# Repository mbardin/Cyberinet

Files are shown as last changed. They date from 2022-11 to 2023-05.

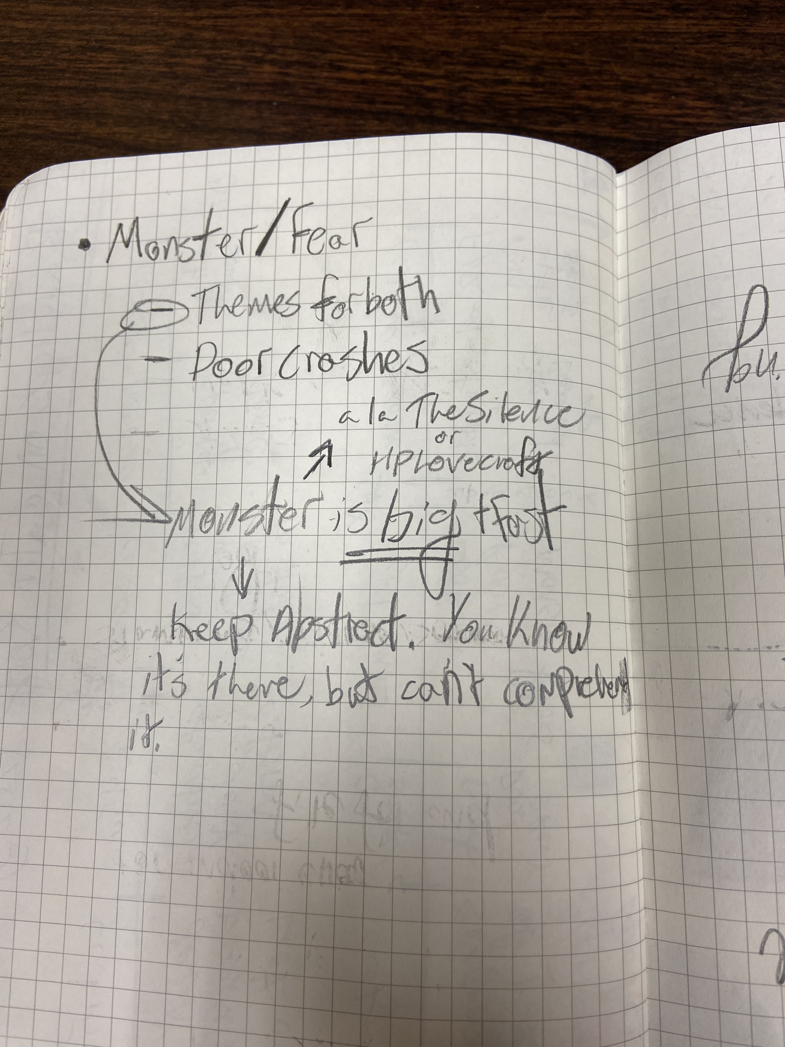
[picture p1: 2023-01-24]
zMusic Composition Scores/scores/materials/raindrops/planning diagrams/IMG_1224.JPG

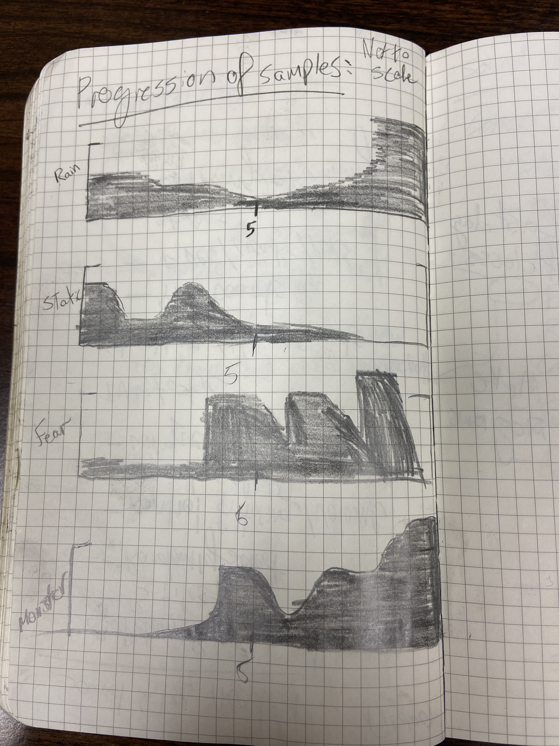
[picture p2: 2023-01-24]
zMusic Composition Scores/scores/materials/raindrops/planning diagrams/IMG_1223.JPG

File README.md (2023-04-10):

# Cyberinet: Integrated Semi-Modular Sensor Interface for Computer-Augmented Clarinet
 Collection for all assets related to the Cyberinet
 
 A Dissertation Project by Matthew A. Bardin [2023]. These Materials are submitted in partial requirements for the degree of doctor of Philosophy in the field of Experimental Music & Digital Media at the Louisiana State University and Agricultural and Mechanical College.

 The goal of the Cyberinet is to bring computer augmentation to the clarinet with minimal additions and adjustments to the performer's traditional practices. The final version is integrated into a special 3D printed clarinet barrel that can easily replace the standard barrel to instantly add augmented capabilities to the instrument.

 ## SYSTEM COMPATIBILITY
 Versions 1.X currently are only supported on Mac OS operating systems. This is mainly due to how Windows-based systems handle incoming and outgoing serial communications. This problem could potentially be worked around by a user with sufficient knowledge of those systems, but it is the main priority to have the Cyberinet easily functional on all main operating systems for version 2. Outside of the serial communication, all of the other Cyberinet software components are compatible with both Mac and Windows.

 ## FIRST TIME INSTALLATIONS
 When utilizing the Cyberinet for the first time, a few items will need to be installed on your device. First, if you do not have Node and the Node Package Manager (NPM) installed, these will need to be included for the data transmission. You can check the installation in the Terminal program on Mac devices. Typing the prompt `which npm` will return the version of npm installed on the device. If the program is not installed, the terminal will indicate so. You can install npm with the terminal command `npm install`, or at https://nodejs.org/en/download

 Once this is installed, there are only two more steps. Next, if you do not already have it installed, install the Arduino IDE from https://www.arduino.cc/en/software. This is the program used for programming the Cyberinet and can be utilized for easily installing the microcontroller drivers. Once installed, navigate to the IDE's preference menu, and notice the item labelled `Additional Boards Manager URLS` and enter the following url in the box: `https://espressif.github.io/arduino-esp32/package_esp32_index.json` When complete, you can navigate to the IDE's Board manager and install the ESP32 library that will now appear in the board manager. Once this is installed, you will not need to use the Arduino IDE again unless you wish to reprogram or make a duplicate of your Cyberinet.

 If you do not currently have Max installed, it can be downloaded from https://cycling74.com. The program can be purchased, and has an educational discount, but purchasing is not required unless you wish to program your own patches for use with the Cyberinet. Patches made by others can be utilized without purchasing the software.

 The final installation will be covered as part of the wireless communication section of this document.
 
 ## Wireless Communications
 The Cyberinet communicates with a host computer using Bluetooth connectivity. The device will appear as "CyberinetVXX" indicating the software version. 
 _As a trouble shooting tip, before performing with the Cyberinet first un-pair and re-pair the Cyberinet with the host computer._ 

 To begin communications, first power the device and navigate to your computer's bluetooth preferences. Select the Cyberinet to pair with the device.
 Then, open the object `CNET.test` in Max. This object is designed to help with setting up the Cyberinet and ensuring the communications can be received. Follow the instructions in the patch, but keep note of step 0. If you have not utilized node scripts in Max previously, you will need to install the final component by sending a bang into the right-most inlet of the object (right-most button in the test patch). From there, you can begin Utilizing the Cyberinet by following the on-screen instructions. 

 When listing the available communication ports, you will see them listed in the Max console. If it appears as something other than `/dev/tty-CyberinetV13` (the final number indicates the software version), then enter the given port name in the provided message box prior to enabling the communications.

 ## Device Ports
 The internal Lithium Polymer battery can be charged with the Cyberinet's USB-C port. The device can function while charging, but only transmits data using Bluetooth communications.
 The ESP32 DEVKIT contains a micro USB port. This is only utilized for flashing adn updating the microcontroller, and is not accessible without disassembling the device.

 ## Printed Circuit Boards
 The Cyberinet is available for purchase including all of the components pre-set up. However, the materials are all open source and can be created using the included PCB diagrams, Arduino code, and other materials in this repository.
 
 ## OEM Components
 The Cyberinet contains the following OEM Components listed in the BOM:
 * ESP32 DEVKIT V1
 * MPU 6050 6-axis Gyroscope
 * TP 4056-C
 * SparkX Differential Pressure Sensor 

  _A second troubleshooting tip. If the Cyberinet does not power on when the button is pressed, first try pressing the button 4 times in a row. If that does not work, connect the Cyberinet to a charger. A short connection can be enough to jump the device to life, but it is recommended to fully charge the Cyberinet immediately prior to a performance._ 
 
 ## Hardware
 The casing for the hardware is 3D printed. .stl files can be found in the repository. The form factor of the Cyberinet is designed to temporarily replace the barrel of a traditional Bb clarinet.
 You cn also find the .gcode files for the 3D printed hardware here as well.
 
 ## Code
 The Cyberinet is programmed using the Arduino IDE. The main unit comes with the most up-to-date firmware version already included. Reprogramming the Cyberinet is not recommended as accessing the necessary port will result in the permanent unsealing of the device, which will lead to rattling in the unit and potential damages due to any internal gluing and other supports being altered.
 
 ## Max Patches
 The included Max patches can be used to create various audio and visual processes using the data received from the Cyberinet. Several examples and help patches are currently in development.

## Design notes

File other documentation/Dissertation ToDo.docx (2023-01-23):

# Hardware

- Order more ESP32, airflow boards, gyro, and power boards
- Choose connector type
- Finish soldering main and button boards
- Design box with new size measurements
- Model version of box with and without mouthpiece. See which one works the best
- Buy batteries. As big as possible while fitting in the container
- Design pitch sensor

# Software

- Create reverb
- Create compressor
- Create filter
- Create delay
- Create pitch analyzer

# Music

- Revise first two comps
- Make ethereal score pretty
- Make puzzle score pretty
- Write and format raindrops

# Document

- Discuss all 3 music comps
- Break down the build and software
- Historical context

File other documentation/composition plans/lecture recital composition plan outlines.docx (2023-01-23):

# Ethereal presence:

Music material comes from my bass clarinet concerto with expansions for a better flow

Uses gyro/accel to control the synth

Mixes between longer, slower tones and fast runs.

Extremely open structure. Idea is that each performance will be different.

Two main synth types: more textures and melodic. May look into fixing to certain pitches a la auto tune.

# Puzzle of a Park:

A loop pedal style. Performer uses the two main buttons to trigger recording and playback

How the buttons work:

Performer needs to start the recording and playback in time.

Control mixing of the 4 voices via air flow

# Raindrops on a Tin Roof:

Longer than the other two compositions. Utilizes everything except the buttons

SCARY

Control the triggering of sound files with pitch analyzer portion of the device

Control mixing of various playback with airflow

Control timbre with gyro

Control tempo with accel

Have pages of score broken up between 3 different stands with rapid running between sections

Rain and wind sounds as part of backing

Trigger monster and other ambience sounds with pitch analysis

Run between stands to make more out of breath over time. This change will trigger more monstrous playback transformation

Follows the story in terms of structure:

1. Rainy night
2. Falls asleep and wakes up
3. Things not quite right
4. Goes to basement
5. Finds monster
6. Runs away
7. Monster changes
8. Gets to top floor
9. Followed
10. Panics and runs outside before being killed

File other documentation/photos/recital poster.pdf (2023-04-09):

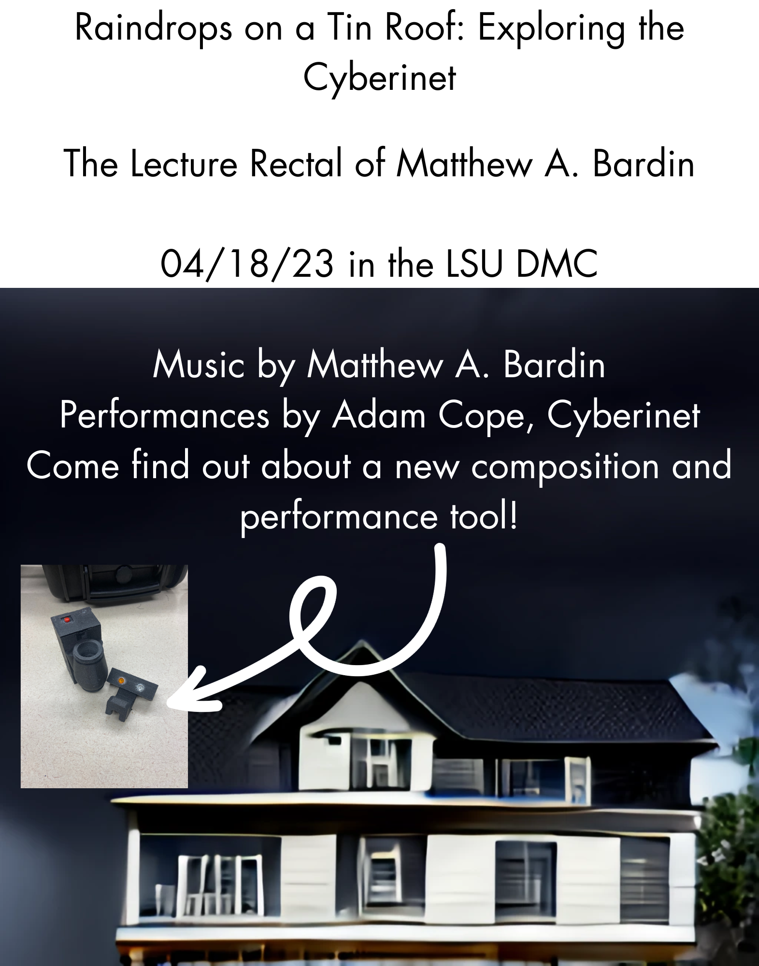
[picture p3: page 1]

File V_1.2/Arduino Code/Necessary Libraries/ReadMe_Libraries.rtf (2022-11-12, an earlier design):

Readme: Cyberinet Libraries

If you would like to change the code running on your Cyberinet, or need to update the code, you will need the libraries included here in order for the code to compile.

First make sure that your board is set to “DOIT ESP32 DEVKIT V1” and that the following libraries are included:
Wire : Installed from the Arduino IDE Library Manager
Sparkfun_SDP3x_Arduino_Library : Must be installed from .zip folder
BluetoothSerial : Installed from the Arduino IDE Library Manager
MPU6050 : Install from the Arduino IDE Library Manager

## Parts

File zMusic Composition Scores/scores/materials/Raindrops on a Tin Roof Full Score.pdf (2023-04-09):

# Raindrops on a Tin Roof

# for Cyberinet, pre-recorded sounds, and live electronics

# Matthew A. Bardin

2023

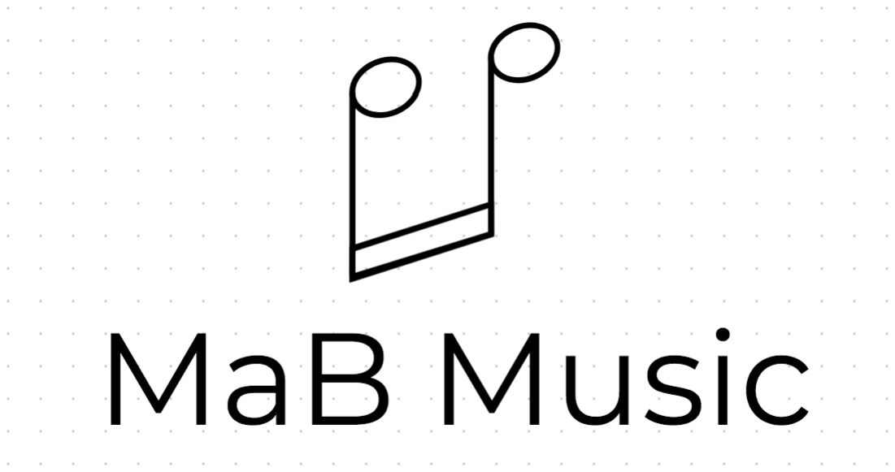
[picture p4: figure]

Program Note:
A short story. An event. When you are the most comfortable, that is when the unknown can strike. Usually in a way we least expect. How can one respond to the uncomprehendable?
Approximately 12-15 minutes in duration. Completed March 15

th 2023 in Baton Rouge, LA MaB

Performance Notes:
For the Performance of Raindrops on a Tin Roof, a unique setup can be utilized. The theatrical stage setup is not required, but highly encouraged by the composer if possible as they enhance the atmosphere.

The performer should arrange three stands across the width of the stage. When instructed in the score, the performer should move from their current stand to the indicated stand. A smoke machine should be placed upstage and off-center of the performer to minimize its visibility from the audience. The smoke machine should be set to approximately medium-low. There should be a low mist/fog that picks up the lights in the room, not so much that it becomes obstructive.Two DMX-controlled lights should be placed slightly downstage of the performer, illuminating the stage. Stage lights should be turned off, but if needed spotlights, stand lights, or low-level lighting can be used to illuminate the three stands for the performer. Will all of the staging, the performance space should look like this:

Smoke Machine

3 | 1 | 2
Light | Light
| Audience

The following Performance Pages should be on the stands as shown below:

1. Pgs 1-2, 4-5, 9-10
2. Pgs 5-8
3. Pgs 2-4

Multiple stands at some stanf locations may be needed.

Adjustments to the staging can be made depending on the specifics of the performance venue. The atmosphere should be spooky, and as if rain will begin at any second. A fan is recommended to help dissipate the smoke following the performance.

Tempo markings should be observed as close as possible. Tempi indicated are those of the synthesizer accompaniment sound files. When the “as fast as possible” instruction occurs, the performer should play the section as fast as possible while still maintaining rhythmic and pitch integrity. Do not worry about playing in time with the synthesizer during these moments. There will be a moment to return to being in time with the synthesizer indicated with the button.

On Software:
The Raindrops on a Tin Roof Max Patch is required for the performance. This patch can be downloaded from matthewbardin.com/raindrops. If needed, Max (Version 8.5 or newer needed) can be downloaded from cycling74.com. It is not required to purchase the software as the patch will run in demo mode, however it is recommended if possible as purchasing the software will unlock editing and saving of patches.

The Max patch will take data from the Cyberinet’s embedded sensors and use them to process sounds as shown below:

Gyroscope: Used to control reverb and panning Accelerometer: Used to control DMX Lights, playback volume, and delay Airflow: Used to control DMX Lights, playback volume, and distortion Button 1: Used to cycle through settings and trigger audio clips Button 2: Emergency Mute All switch

Largely speaking, the Cyberinet controls the volume of various sound files on playback, as well as the processing to those sound files. The clarinet timbre is the only element with no processing applied to it.

There are three categories of sound files used in Raindrops on a Tin Roof:

1. Synthesizer Accompaniment: Unnatural, distorted sounds to accompany the clarinet timbres.
2. Ambiance: Digetic sounds occurring in the story as it unfolds. These include rain sounds, monster sounds, and creaking floorboards
3. Narrator: Recordings of the composer reading the story. These are used to provide context to the music as it is happening. Generally the music pauses during these moments.

On Hardware:
The performer will need the Cyberinet as well as the button expansion to perform Raindrops on a Tin Roof. In addition to the items listed under ‘Performance Notes’, The performer will require a computer to run the software patch. This computer can be either Windows or MacOS. The software patch will run on either devices. A USB-to-DMX adapter for each of the lights are also needed as they will be controlled from the max patch.

On Notation:
Cross Noteheads: Indicate pressing Button 1 to progress to the following section of music.

Vamp: Repeat the indicated music as many times as wanted or needed. Each vamp should occur at least 3 times. All other repeats occur once.
Travel Instructions: Tell the performer their method of moving from one stand to another. This text is always underlined.

Movement Indicators: Indicate exaggerated movements or breathing.
Exaggerated movements should generally be swaying or small steps to trigger the gyroscope more.

Exaggerate breathing should be heavier and more frequent breaths than normal in order to further trigger the airflow sensor. Take care not to hyperventilate.

Synthesizer parts: Are not intended to be performed by a person. The part present in the score is the notation of the accompanying sound file. This notation does not reflect the specific processing applied to the sounds as that will change with each performance, but general indications are given to help the performer stay in time with the accompaniment.

Narrator Text: Text indicators for the narrator files are printed in the score. The first and last line are printed; separated with an ellipsis (...). The duration of the file is also provided. This text is always boxed and italicized.

Metric Relations: eighth notes are constant throughout whenever a time signature change occurs.

Print Versions of the score arrive hole punched for storage, but are kept loose for arrangement on the stands. Extra copies of necessary pages are provided.

Narration Full Text:

White flash… 9,10,11… crash!

The storm outside was gradually drawing closer. I lay back in my recliner and sipped my tea. The smell of mint combined with the warmth of the fireplace nearby was soothing. After this past week at work, I was looking forward to relaxing. Another flash of light. …7,8…crash!

This storm was oddly out of season, but not unheard of. At most a few trees get blown over and knock out the power, maybe a little flooding in the lower areas of town, but nothing that isn’t resolved and forgotten within a few days.

I sat there, sipping my tea, enjoying the solitude and relative silence of the house. It was around this time that the sound of the rain began to reach me. The sound grew so gradually that I have no idea when it really started, but by the time I had finished my tea and the final chapter of my novel, the sound, filtered through two floors of family history passed down along with the house, the sound had developed into a dull roar of water droplets on my house’s metal roof. It was constant, yet soothing. Maybe the storm would be a quick one. The floorboards creaked as I walked over to the window.

4,5,6,7…

The timing between the lighting and thunder was getting closer and closer. Hopefully this would move past without too much trouble, but it didn’t seem to be moving any faster than before. (1:32)

I decided to take a break from reading and turned on the TV instead. Flash… 3,4,5… crash!

The thunder had startled me awake, and I was both a little groggy and confused that I had fallen asleep so unexpectedly. The long days at work must have worn me out more than I originally thought. The TV was displaying nothing but static. The storm must have knocked something out in town. At least the power was still on for now. The rain was still coming down as a dull roar on the roof; blending with the static from the television.

Glancing outside, I saw that it was pitch black from the storm in the night. That made since; I had been out for several hours at this point. I shivered a little and drew the curtains shut as the kettle began to boil. Crash! I didn’t see the lightning, but the thunderclap sounded as if it was right above the house. A few minutes later I returned to the living room, steaming mug in hand. When I returned to the TV, it was still displaying static. (0:57)

As I sipped my tea, there was another clap of thunder and the TV suddenly cut out, plunging the whole room into darkness. Cursing a little, I stumbled my way around the room trying to find the light switch. By the time I go to it, I had stubbed my toe and tripped on several small items I couldn’t see on the floor. I didn’t think I had left anything on the floor before I fell asleep, but the darkness was extremely disorientating. I had probably knocked something over without realizing it when I first woke up.

Click… Click, click, click. Great.

It wasn’t just the TV but the entire power supply was out; probably for most of the town by this point. The rain kept coming down. I could no longer see the white flashes from the lightning but could hear the claps of thunder, much louder than before. I fumbled my way out and down the hall, trying to find the basement door. It was strangely dark.

Despite living here for almost my entire life, the storm seemed to turn the place into somewhere I was unfamiliar with. I wasn’t originally going to try and find a lamp downstairs, but the darkness was oppressive and I had almost dropped my favorite mug trying to find a light switch. I didn’t want to trip on something I couldn’t see and fall. With my luck so far tonight, I would end up stepping on the broken shards and near-boiling tea.

Crash! (1:25)

After what seemed like 30 minutes, I had finally found the basement door. There weren’t any more knickknacks knocked onto the floor, but I couldn’t seem to find anything in the dark. Everything felt like it was in the wrong place. I unlocked and opened the door and began to walk down the stairs, the creaking of the wooden steps being the only nose other than the low roar of the rain and the occasional thunderclap.

Creak, creak, creak…

Were there always so many steps to get to the bottom? When I finally got to the bottom of the stairs the roar of the rain had faded away into nothing. Hopefully the fact that I couldn’t hear the rain down hear meant it was passing by. I began to head in the direction of my emergency lights, annoyed at myself for not getting them out before the storm and for leaving my cell phone upstairs. I figured the cell service would be out, but at least those have a built-in flashlight. That would have made finding the lamps and fuel much quicker and easier. It was then I noticed that something was in the basement. (1:06)

I don’t remember what it looked like or what kind of sounds it made. In fact, I don’t even remember running away. As soon as I encountered it, my body was filled with something I had never experienced before: in an instant I was dripping in a cold sweat, and shaking as my body filled with a unexpected terror. Just a second ago I was hoping the basement hadn’t flooded, but now there was only one thing my brain and body could comprehend, and it was that I needed to run away as fast as possible. In that moment nothing else mattered. If I didn’t move, I knew I was going to die.

When I reached the top of the stairway, I slammed it shut and leaned against it, panting heavily. The roar of the rain was back, but I could tell that it was gradually fading from what it was before I went downstairs. Or maybe it was just my rapid heartbeat blocking out the sound. It was still pitch black in the house, but now I was able to look around and see, maybe my eyes had finally adjusted; maybe my fear had made my pupils dilate more than they were before. I didn’t care, I was just glad to be able to see. Until I looked around. It was the same house I had seen my whole life, but it was… different. (1:15)

I could see that part of the reason it was so dark was that the windows were boarded up. A layer of dust coasted the walls and floor, and that was all that was there. None of the furniture or pictures remained. Shelves were empty, the TV and recliner were no longer in the living room, visible through a half-open door at the end of the hall. I locked the basement door and took a small, caution step forward and immediately winced. I looked down and cursed again. In my rush I had apparently dropped my mug and stepped on one of the pieces; just like I knew would happen. It wasn’t a deep cut and was barely bleeding, but it hurt now that my adrenaline was fading. What had I been so scared of before? (0:43)

I must be extra jumpy from my lack of sleep this week. The basement was mostly just storage, nothing could get in there. I was just about to turn back around to get the lamps again when I felt it: the fear was coming back. I couldn’t remember what the thing in the basement was, just that I had to get away. (0:19)

I could feel that this thing was right behind the door, and that it wanted me. I immediately broke into a sprint to the kitchen window since it was the closest way out of there. I didn’t care where I ended up as long as I was away from here. The pain in my foot was inconsequential now and I ignored it as I ran. I didn’t even notice the small trail of blood following wherever I went. There were no other emotions that fear. I had to escape.

It was no good, the kitchen window was boarded up too tightly to squeeze through. Changing plans, I hurried towards the front door at the oppilate end of the house, making sure to cut through the living room to avoid the basement, but that was also boarded up. I fumbled with the lock, trying to get it open and pry off the boards on the outside. The rain seemed excruciating loud, but I could almost taste safety on the other side of the door.

CRASH! (0:54)

The basement door broke open with a crack much louder than any of the thunder I’d heard so far. Giving up on the door, I immediately ran up the stairs to my left to the second floor. Knowing whatever it was would only be a few moments behind me I wished I had another door to shut to slow it down, if only for a second. As I ran, I could hear the rain on the roof crescendo

All the windows were boarded up, and other than a layer of dust the only thing in any of the main rooms was a large dark stain on the floor of what was my bedroom. It was quickly obvious that I would not find a way out here so I bolted, limping slightly from the pain in my foot. If I could get to the veranda in the back of the house, I might be able to shimmy down the side of the building to safety; assuming I didn’t slip in the rain. It had a glass door after all so I could use my body to break it open. What was a few more scrapes at this point? (1:04)

As I ran, I could feel it getting closer. By this point it was on the second floor with me as I hurried to the door. The closer it got, the more horrified I became. The sound of the rain was almost deafening now, but compared to the entity inside with me, it felt like my salvation. Luckily when I grabbed the veranda door handle, it flew open and I tumbled outside onto the balcony. (0:28)

Outside was pouring rain. The dops fell hard and stung. This constant firing of miniature bullets was painful, but I barely noticed. I needed to find a way out of the house. Out of the neighborhood. Out of the entire town. I was looking around for a drain pipe or a ledge to shimmy across when I noticed it: the view. The trees normally extend through to the hill line below and to the end of my sightline.
They were gone.

The trees weren’t cut down, or replaced by new building, they were just gone. At the end of my backyard the world seemed to just vanish. I couldn’t tell if it was simply too dark to see that far or if my house had been teleported to some other dimension that was pitch black and full of nothing but swirling storm clouds, thunder, and rain. I suppose in the end it didn’t really matter. (0:52)

As I was looking for a way to run away, I could feel it: the same feeling I had in the basement. This terror resonated with me to my core. This was something that felt baked into my very being, something at a baser level than any human logic. Pure, unfiltered fear. I knew that whatever the thing was it was now right behind me on the other side of this last door. I stopped and looked up at the rain. At this moment the rain suddenly let up. I could see the stars through the eye of the storm and as the sound of the raindrops stopped, only to be replaced by the crashing of the veranda door being knocked open. (0:53)

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

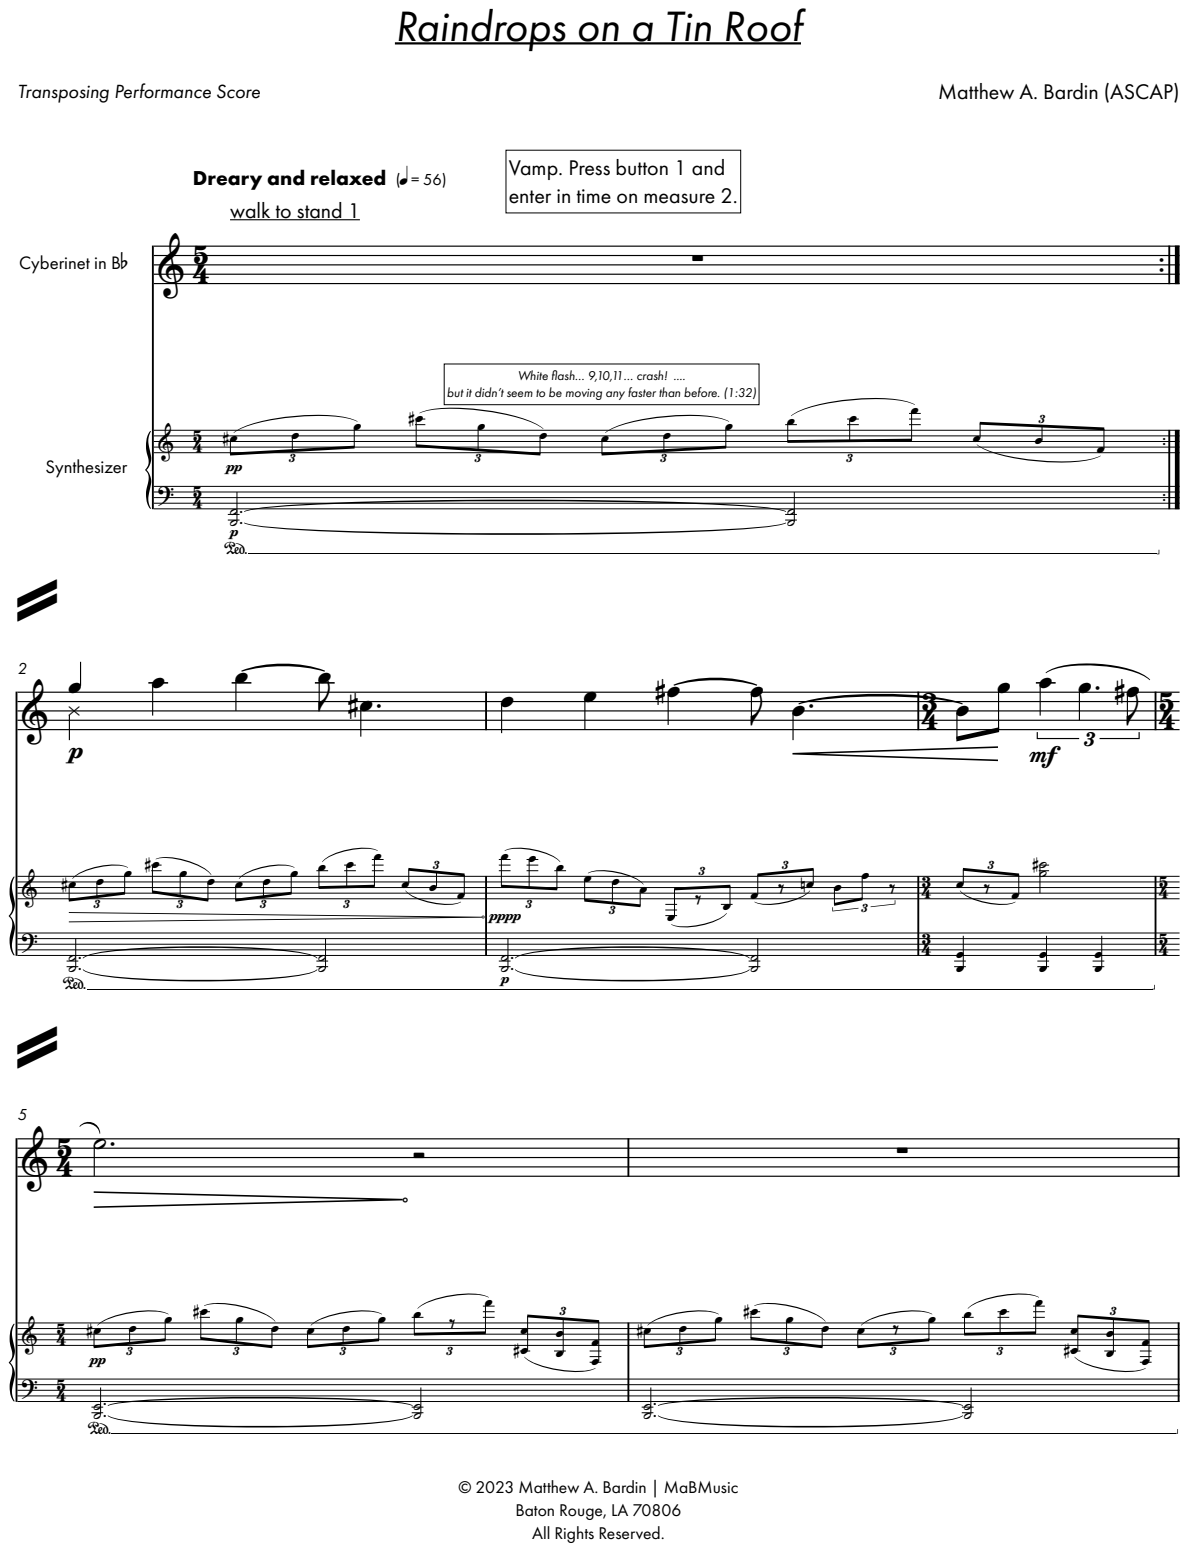
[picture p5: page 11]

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

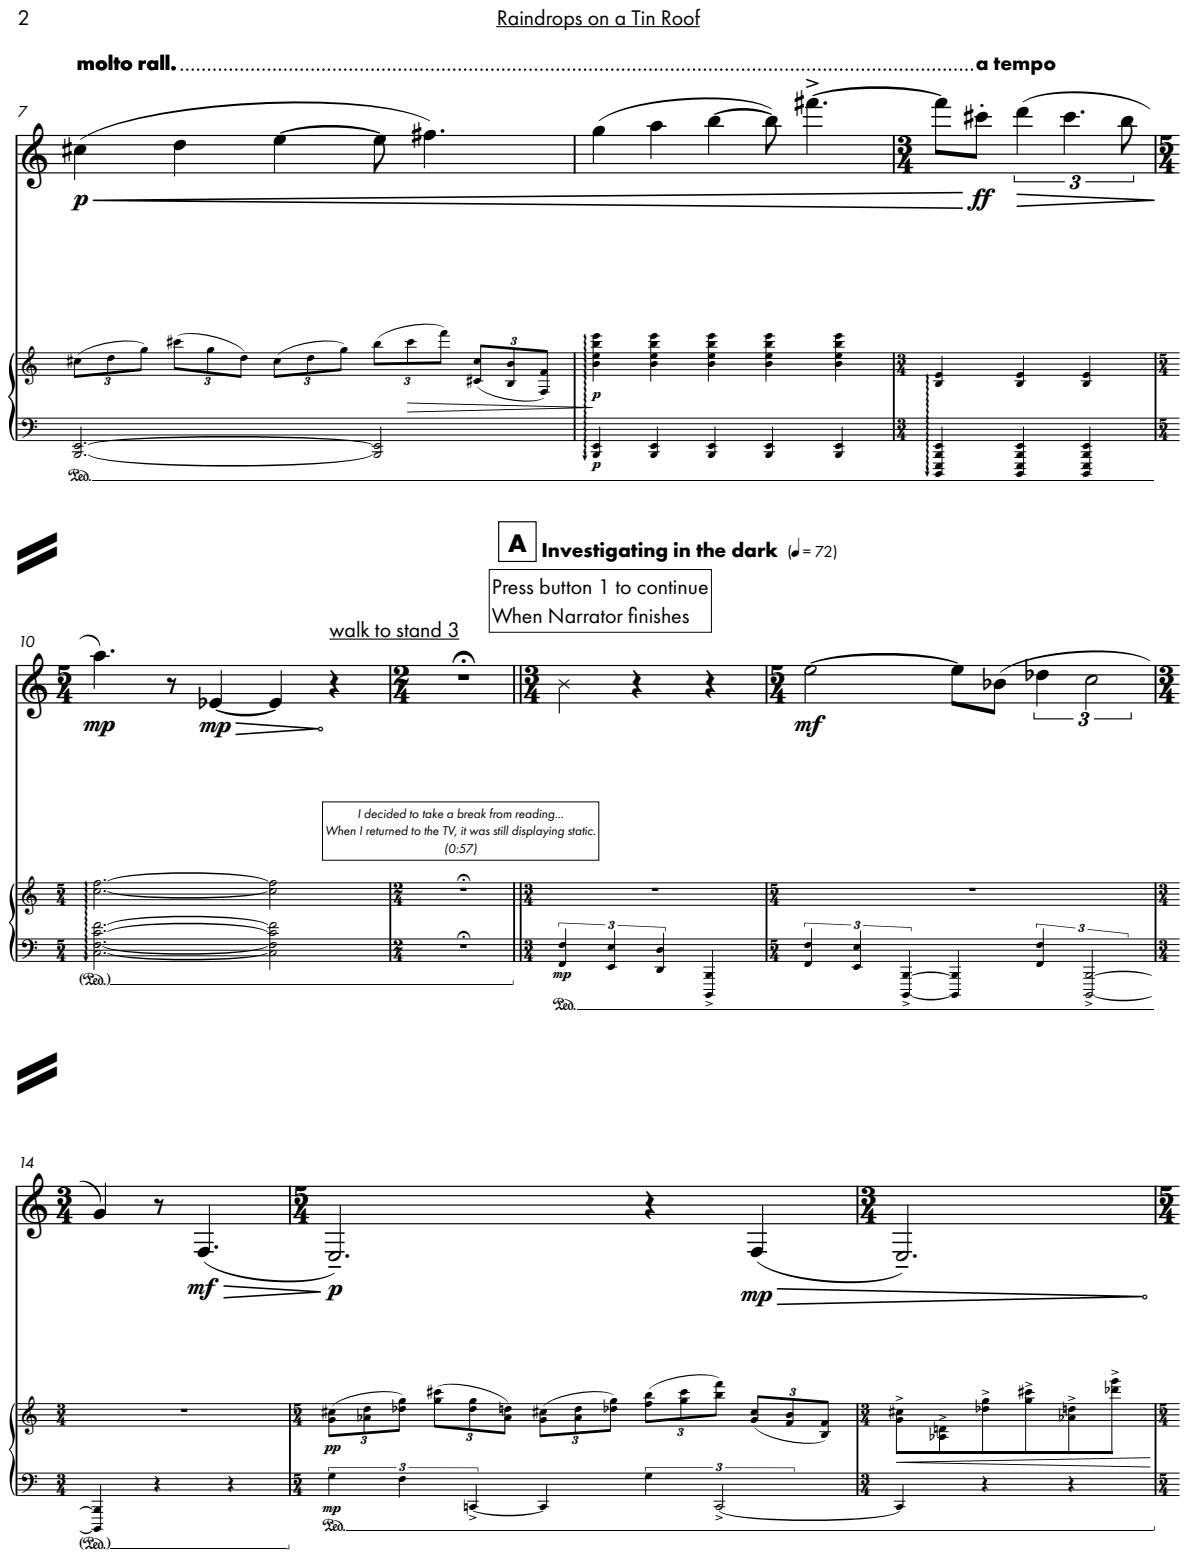
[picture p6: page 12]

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

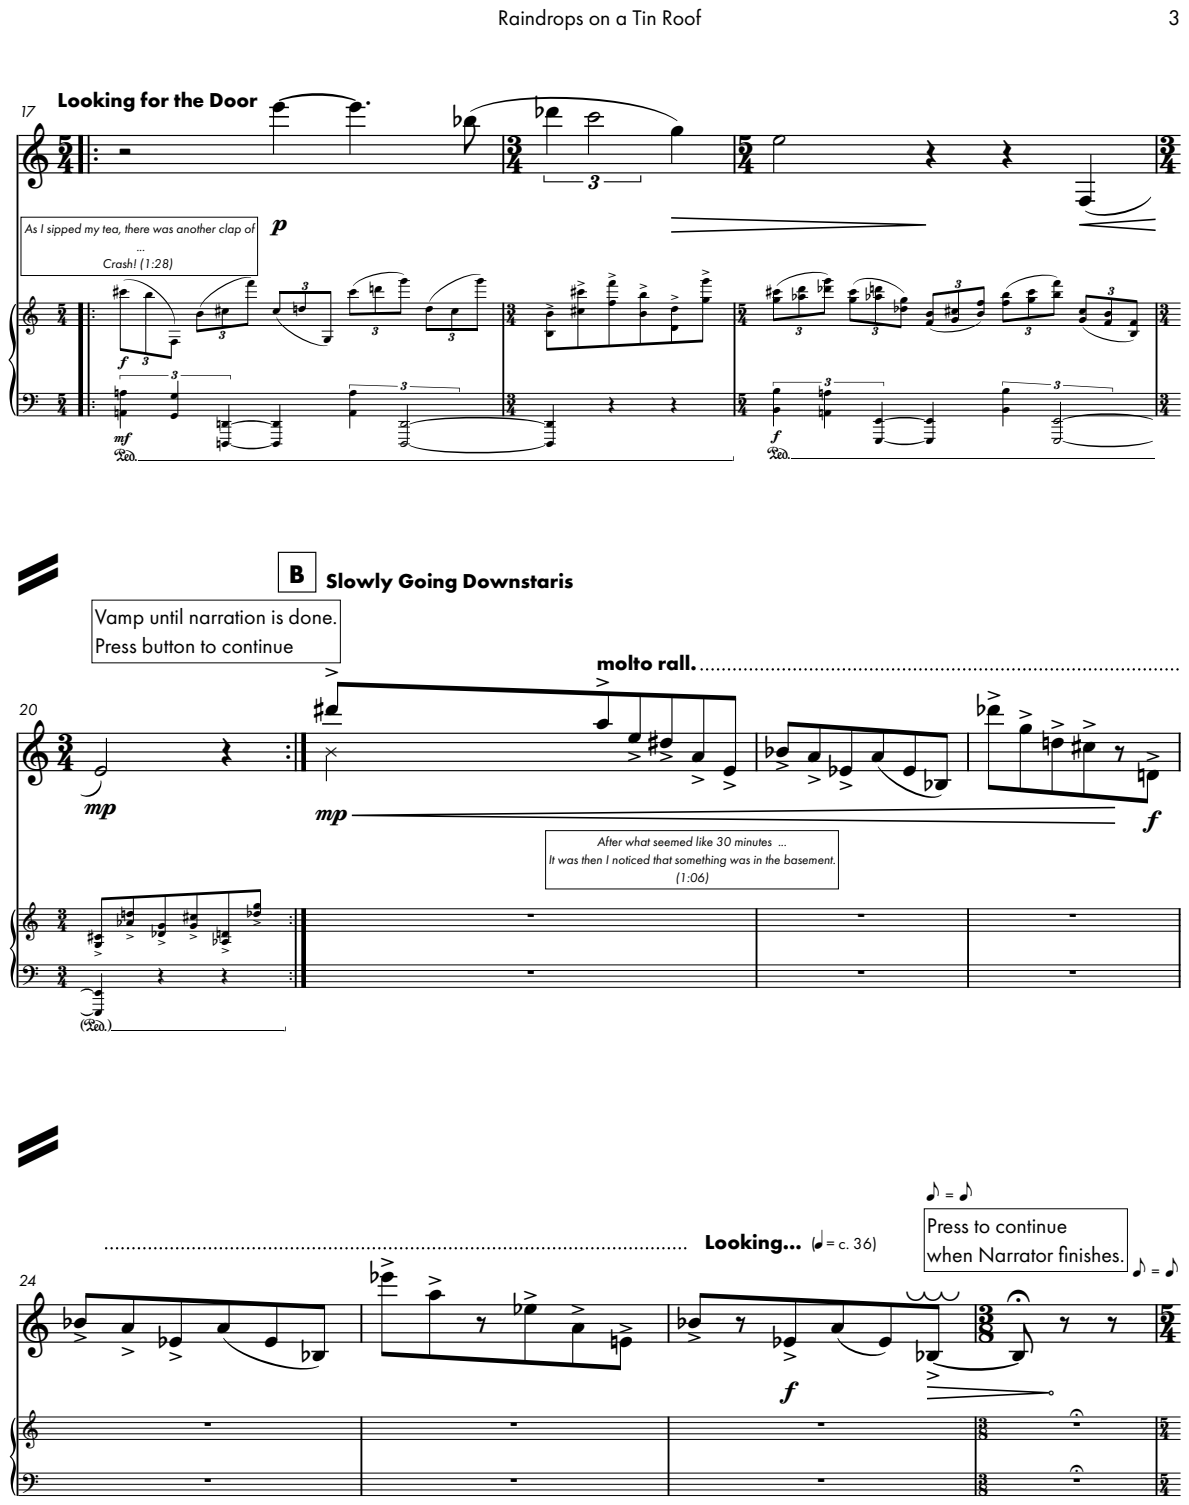
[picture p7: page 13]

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

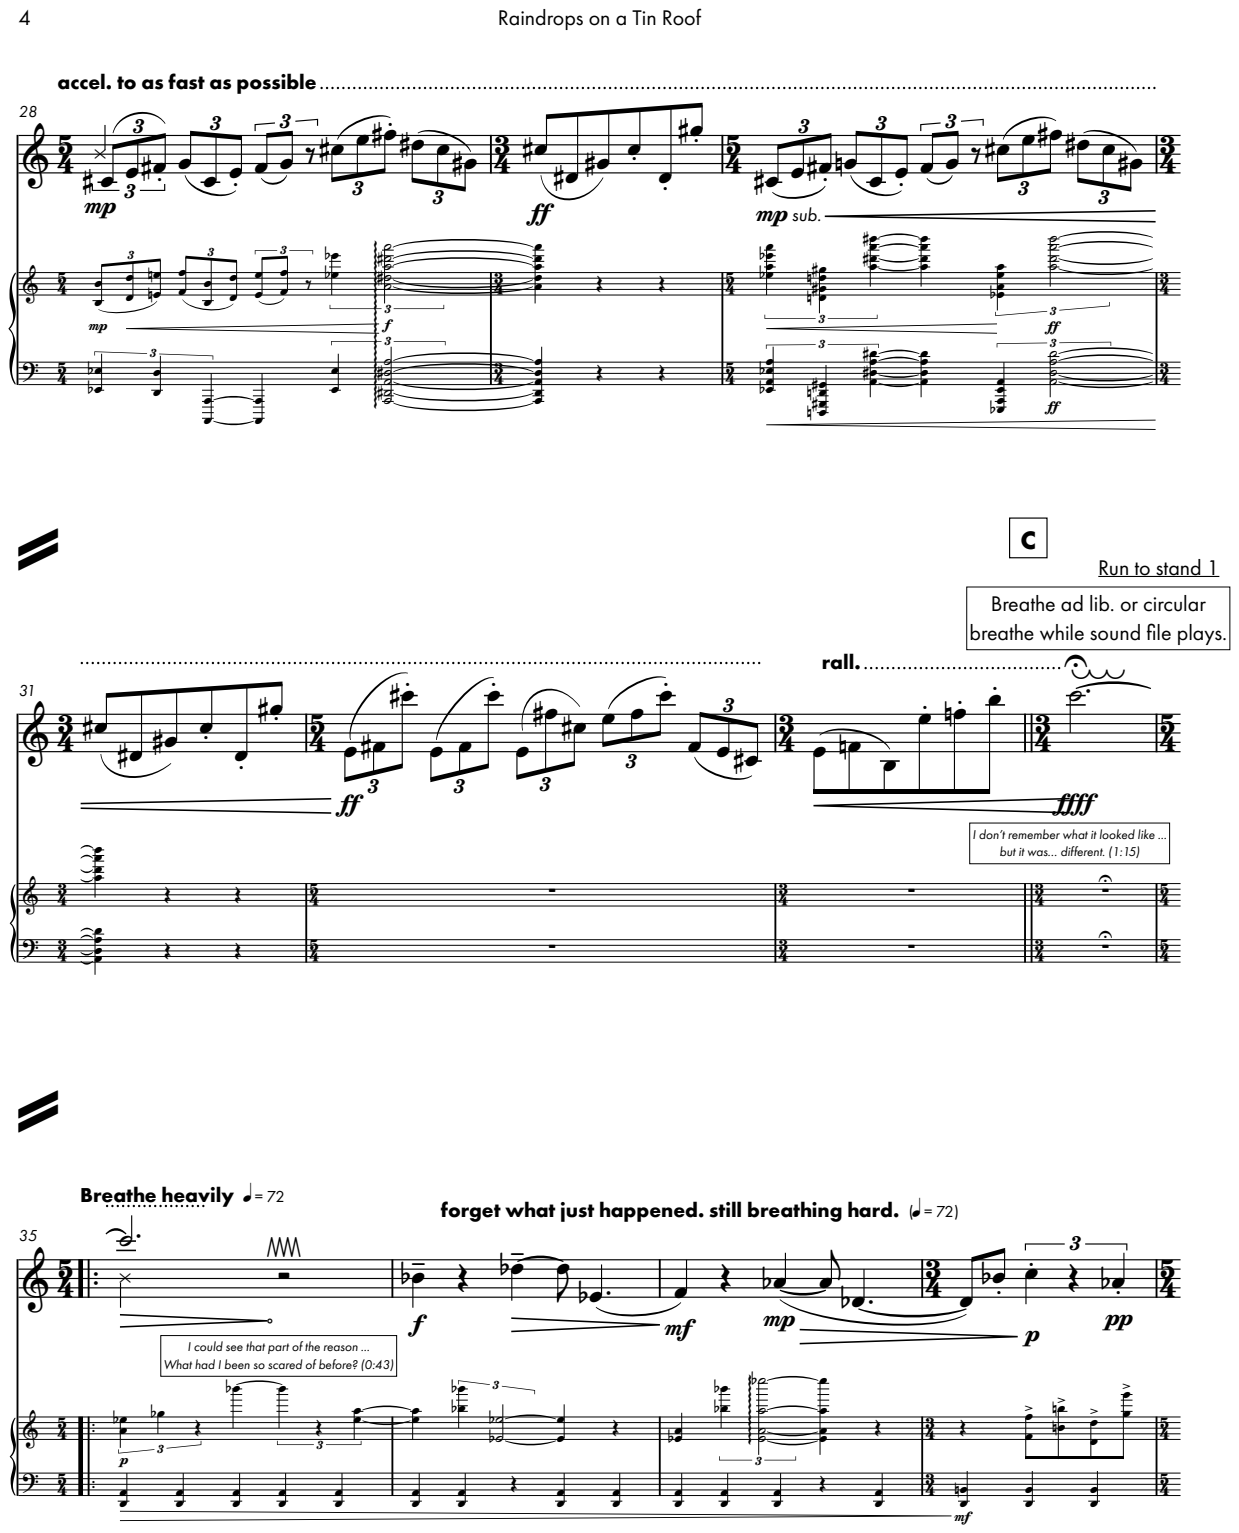
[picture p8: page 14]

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

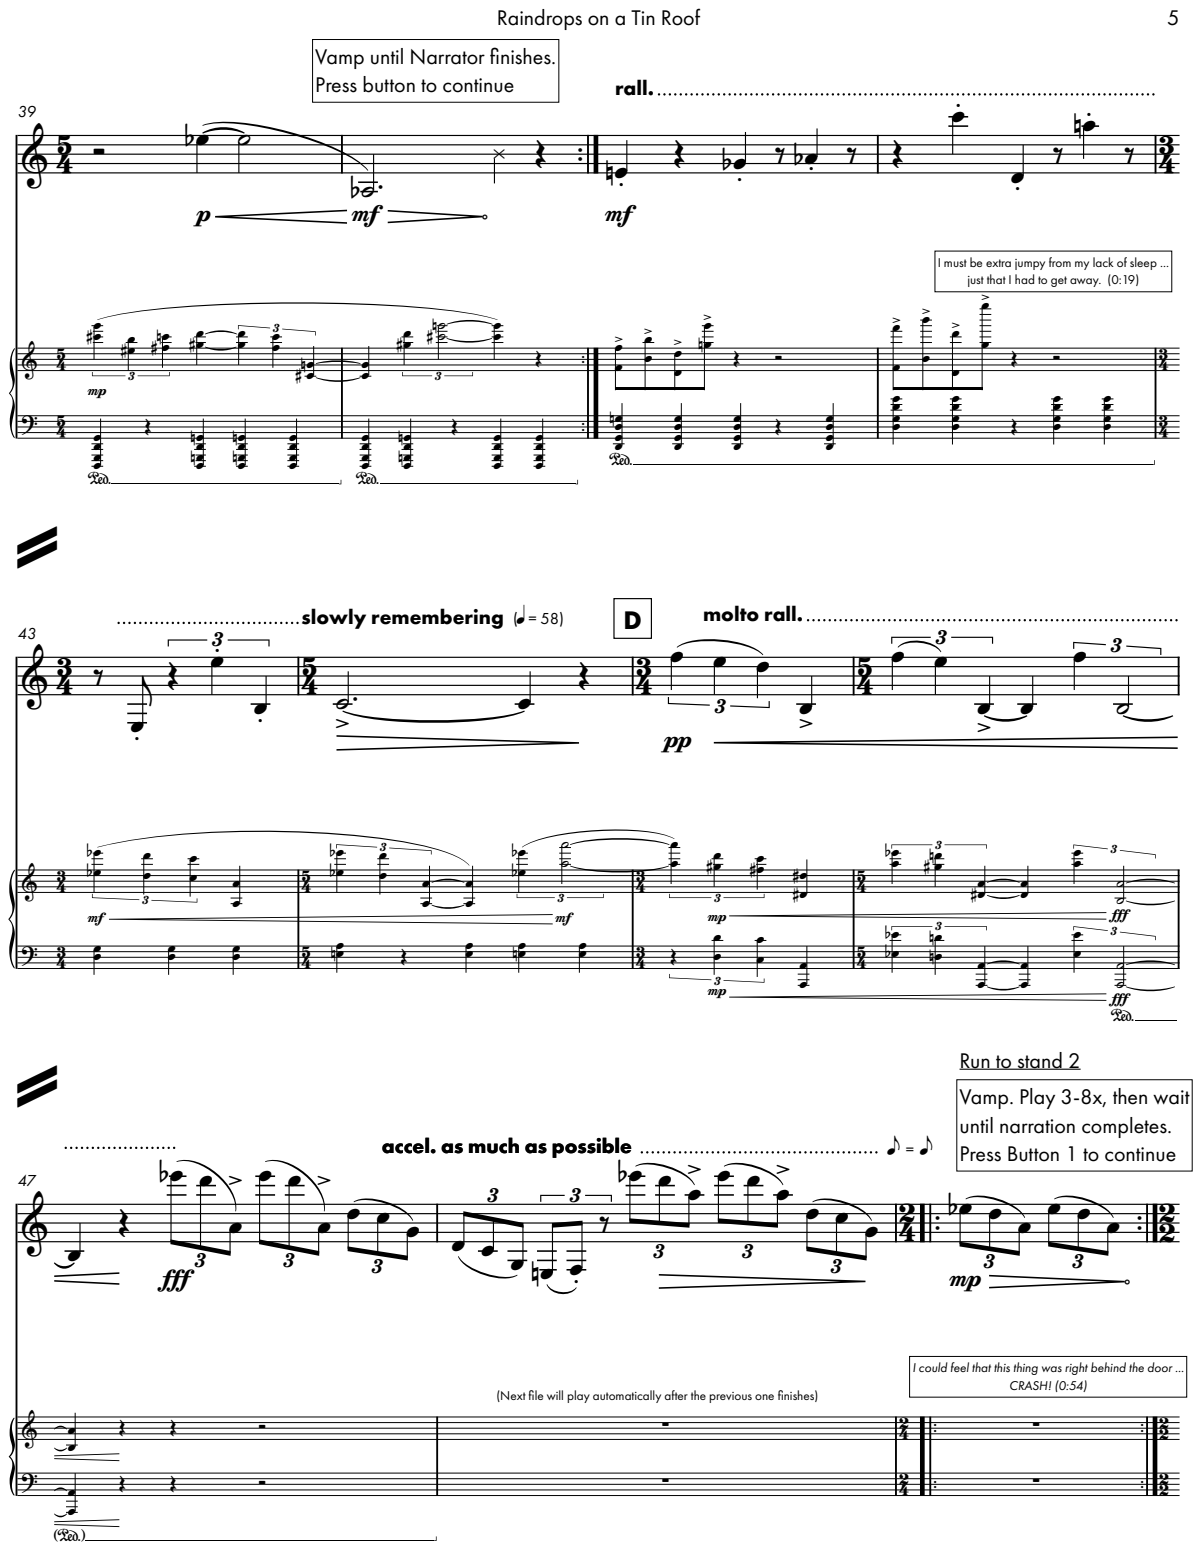
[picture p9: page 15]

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

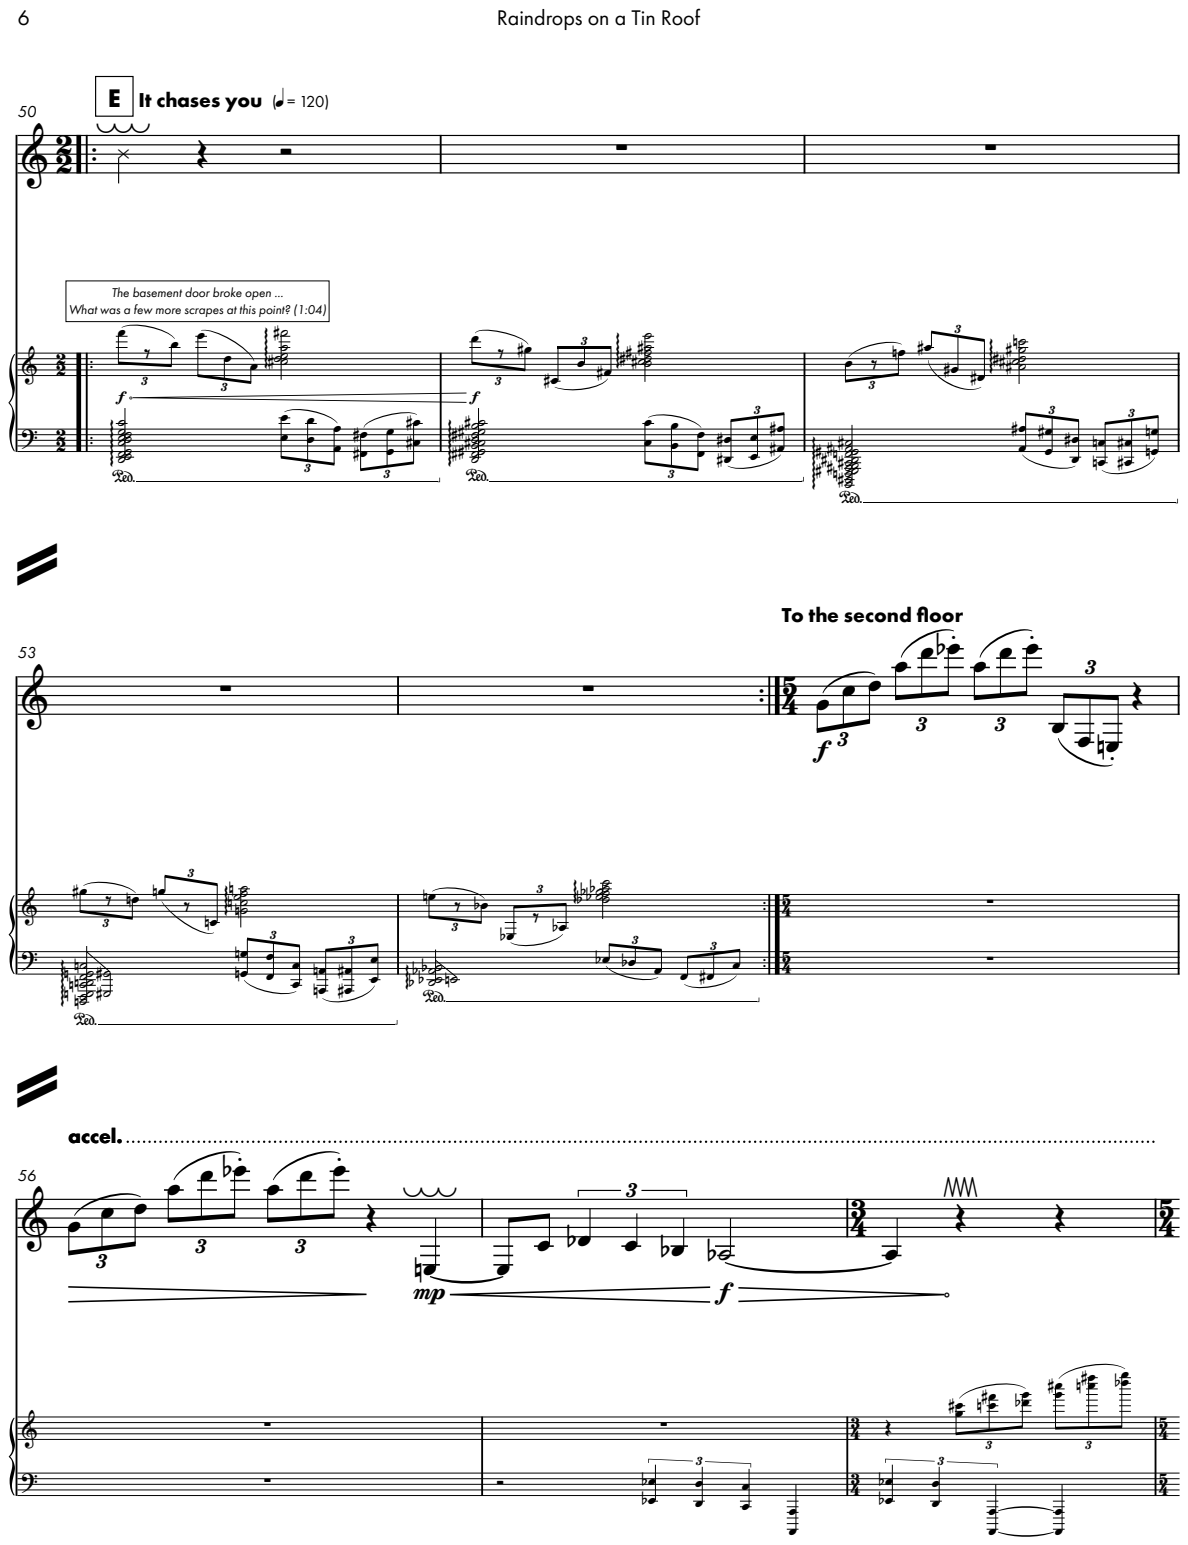
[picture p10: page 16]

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

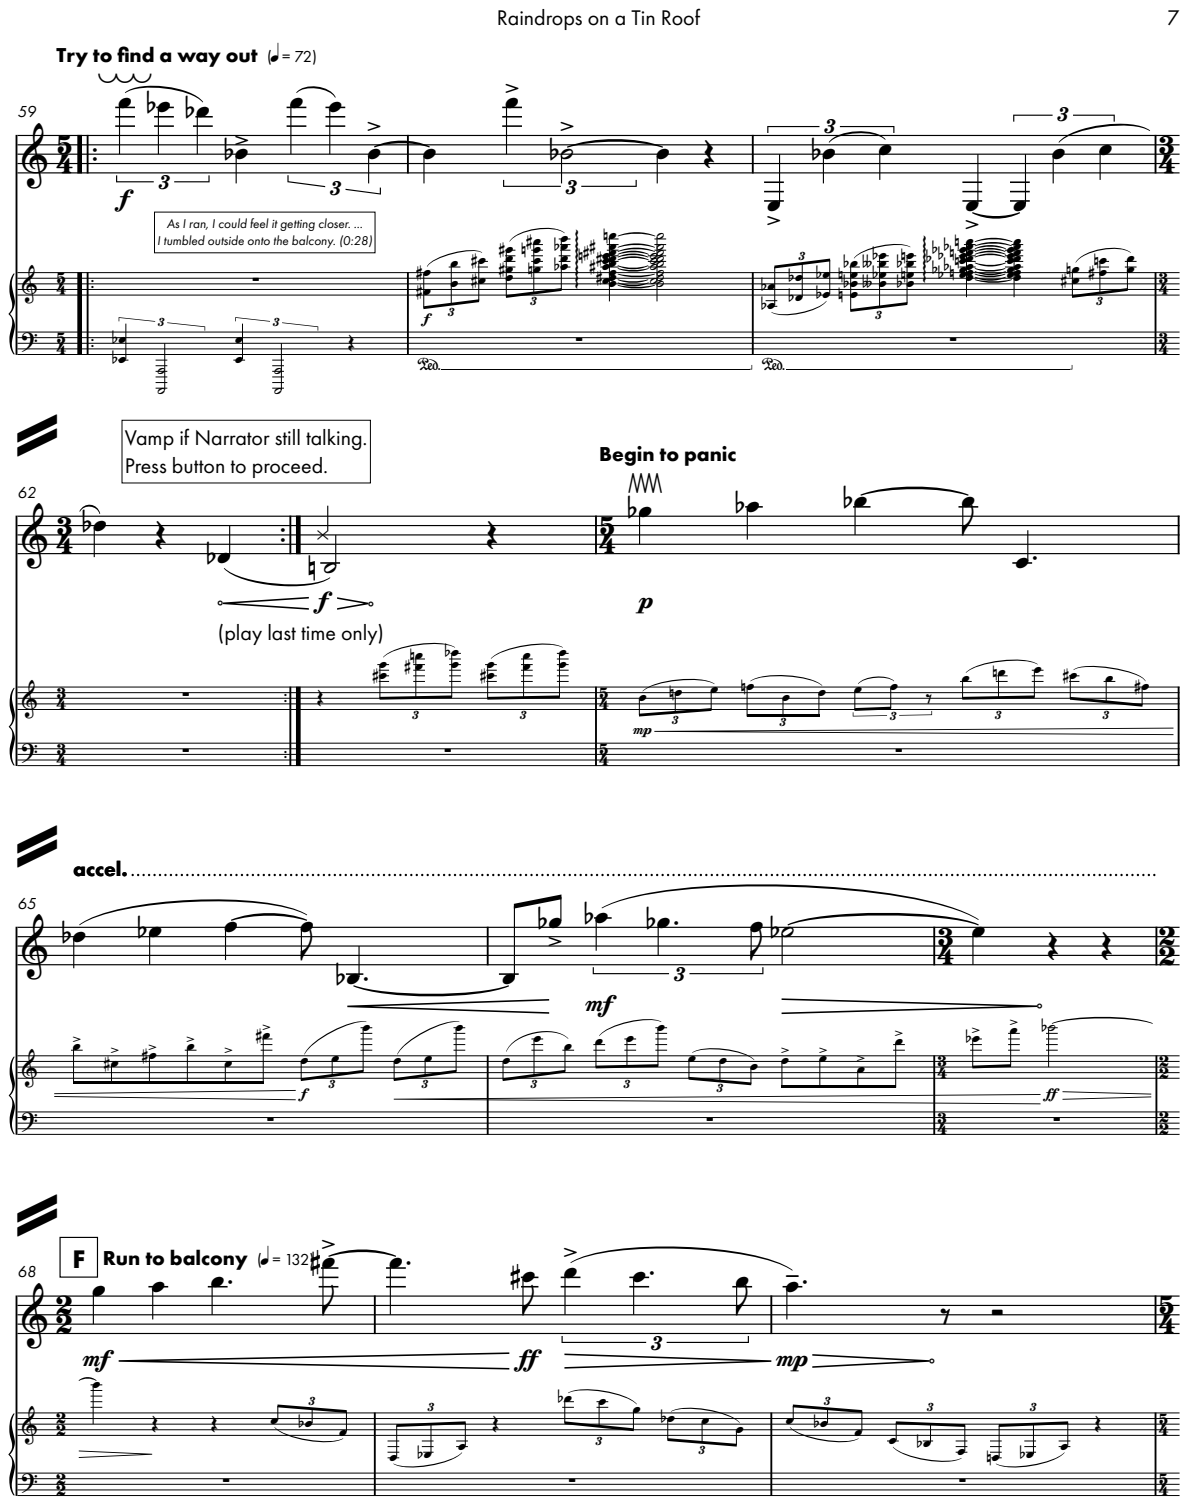
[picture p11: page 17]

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

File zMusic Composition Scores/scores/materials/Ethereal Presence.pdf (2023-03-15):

# Ethereal Presence

## for Cyberinet

## Matthew A. Bardin

2023


Program Note:
It is impossible to do anything in a complete vacuum. Others affect you, you affect others. Living with this is part of the human condition.

Performance Notes:
Tempi are all generalized. The performer can perform the piece at any desired tempo. Accelerando and Rallentando should still happen at the indicated places, but the amount can vary. The goal is a uniquely paced performance; no two should be identical. The performer shoudl experiment with the max patch to find a balance of synthesizer changes that they feel comfortable with, but in general, should have exagerated performance movements to help with the syntesizer automation.

On Notation:
This score uses largely traditional notation. Fermatas and long rests can be held for any duration. Half rests and shorter should be played in tempo.
Double Bar lines indicate different sections of the work and do not imply a pause as the rests do.
Dashed bar lines are provided to help with counting various sections, but may be ignored by the performer if desired.
Niente markings should be performed as quietly as possible while still producing pitch.

Cyberinet Hardware:
This solo requires the use of Cyberinet hardware and software to perform. More informaiton about this equipment can be fount at matthewbardin.com
The Cyberinet hardware replaces the mouthpiece and barrel of the performer's Bb clarinet. The internal sensors collect the following performacne data: gyroscope location, accelerometer speeds, airflow pressure. This data is transmitted to a nearby computer (approx. 25 feet) via bluetooth to control the software portion.

Software:
The max patch for this composition can be downloaded at matthewbaridn.com/Ethereal. The above sensors collect and transmit data to control two synthesizers within the Max environment. The computer running this patch should be connected to an output speaker loud enough to match volume with the Soloist. The first synthesizer generates tones through filtered noise and pitch matching. These produce a textural background. The second produces a variety of tones through FM synthesis and Karplus Strong Synthesis. These tones are intednded to accompany the soloist as a secondary voice.
Because the Performer will perform at differing tempi and styles, they will have unique movements to be picked up by the Cyberinet. This will result in an ethereal accompaniment that is unique to every performance.

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

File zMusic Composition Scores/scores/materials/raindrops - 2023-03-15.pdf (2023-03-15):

# Raindrops on a Tin Roof

# for Cyberinet, pre-recorded sounds, and live electronics

# Matthew A. Bardin

2023


Program Note:
A short story. An event. When you are the most comfortable, that is when the unknown can strike. Usually in a way we least expect. How can one respond to the uncomprehendable?
Approximately 12-15 minutes in duration. Completed March 15

th 2023 in Baton Rouge, LA MaB

Performance Notes:
For the Performance of Raindrops on a Tin Roof, a unique setup can be utilized. The theatrical stage setup is not required, but highly encouraged by the composer if possible as they enhance the atmosphere.

The performer should arrange three stands across the width of the stage. When instructed in the score, the performer should move from their current stand to the indicated stand. A smoke machine should be placed upstage and off-center of the performer to minimize its visibility from the audience. The smoke machine should be set to approximately medium-low. There should be a low mist/fog that picks up the lights in the room, not so much that it becomes obstructive.Two DMX-controlled lights should be placed slightly downstage of the performer, illuminating the stage. Stage lights should be turned off, but if needed spotlights, stand lights, or low-level lighting can be used to illuminate the three stands for the performer. Will all of the staging, the performance space should look like this:

Smoke Machine

3 | 1 | 2
Light | Light
| Audience

The following Performance Pages should be on the stands as shown below:

1. Pgs 1-2, 4-5, 9-10
2. Pgs 5-8
3. Pgs 2-4

Multiple stands at some stanf locations may be needed.

Adjustments to the staging can be made depending on the specifics of the performance venue. The atmosphere should be spooky, and as if rain will begin at any second. A fan is recommended to help dissipate the smoke following the performance.

Tempo markings should be observed as close as possible. Tempi indicated are those of the synthesizer accompaniment sound files. When the “as fast as possible” instruction occurs, the performer should play the section as fast as possible while still maintaining rhythmic and pitch integrity. Do not worry about playing in time with the synthesizer during these moments. There will be a moment to return to being in time with the synthesizer indicated with the button.

On Software:
The Raindrops on a Tin Roof Max Patch is required for the performance. This patch can be downloaded from matthewbardin.com/raindrops. If needed, Max (Version 8.5 or newer needed) can be downloaded from cycling74.com. It is not required to purchase the software as the patch will run in demo mode, however it is recommended if possible as purchasing the software will unlock editing and saving of patches.

The Max patch will take data from the Cyberinet’s embedded sensors and use them to process sounds as shown below:

Gyroscope: Used to control reverb and panning Accelerometer: Used to control DMX Lights, playback volume, and delay Airflow: Used to control DMX Lights, playback volume, and distortion Button 1: Used to cycle through settings and trigger audio clips Button 2: Emergency Mute All switch

Largely speaking, the Cyberinet controls the volume of various sound files on playback, as well as the processing to those sound files. The clarinet timbre is the only element with no processing applied to it.

There are three categories of sound files used in Raindrops on a Tin Roof:

1. Synthesizer Accompaniment: Unnatural, distorted sounds to accompany the clarinet timbres.
2. Ambiance: Digetic sounds occurring in the story as it unfolds. These include rain sounds, monster sounds, and creaking floorboards
3. Narrator: Recordings of the composer reading the story. These are used to provide context to the music as it is happening. Generally the music pauses during these moments.

On Hardware:
The performer will need the Cyberinet as well as the button expansion to perform Raindrops on a Tin Roof. In addition to the items listed under ‘Performance Notes’, The performer will require a computer to run the software patch. This computer can be either Windows or MacOS. The software patch will run on either devices. A USB-to-DMX adapter for each of the lights are also needed as they will be controlled from the max patch.

On Notation:
Cross Noteheads: Indicate pressing Button 1 to progress to the following section of music.

Vamp: Repeat the indicated music as many times as wanted or needed. Each vamp should occur at least 3 times. All other repeats occur once.
Travel Instructions: Tell the performer their method of moving from one stand to another. This text is always underlined.

Movement Indicators: Indicate exaggerated movements or breathing.
Exaggerated movements should generally be swaying or small steps to trigger the gyroscope more.

Exaggerate breathing should be heavier and more frequent breaths than normal in order to further trigger the airflow sensor. Take care not to hyperventilate.

Synthesizer parts: Are not intended to be performed by a person. The part present in the score is the notation of the accompanying sound file. This notation does not reflect the specific processing applied to the sounds as that will change with each performance, but general indications are given to help the performer stay in time with the accompaniment.

Narrator Text: Text indicators for the narrator files are printed in the score. The first and last line are printed; separated with an ellipsis (...). The duration of the file is also provided. This text is always boxed and italicized.

Metric Relations: eighth notes are constant throughout whenever a time signature change occurs.

Print Versions of the score arrive hole punched for storage, but are kept loose for arrangement on the stands. Extra copies of necessary pages are provided.

Narration Full Text:

White flash… 9,10,11… crash!

The storm outside was gradually drawing closer. I lay back in my recliner and sipped my tea. The smell of mint combined with the warmth of the fireplace nearby was soothing. After this past week at work, I was looking forward to relaxing. Another flash of light. …7,8…crash!

This storm was oddly out of season, but not unheard of. At most a few trees get blown over and knock out the power, maybe a little flooding in the lower areas of town, but nothing that isn’t resolved and forgotten within a few days.

I sat there, sipping my tea, enjoying the solitude and relative silence of the house. It was around this time that the sound of the rain began to reach me. The sound grew so gradually that I have no idea when it really started, but by the time I had finished my tea and the final chapter of my novel, the sound, filtered through two floors of family history passed down along with the house, the sound had developed into a dull roar of water droplets on my house’s metal roof. It was constant, yet soothing. Maybe the storm would be a quick one. The floorboards creaked as I walked over to the window.

4,5,6,7…

The timing between the lighting and thunder was getting closer and closer. Hopefully this would move past without too much trouble, but it didn’t seem to be moving any faster than before. (1:32)

I decided to take a break from reading and turned on the TV instead. Flash… 3,4,5… crash!

The thunder had startled me awake, and I was both a little groggy and confused that I had fallen asleep so unexpectedly. The long days at work must have worn me out more than I originally thought. The TV was displaying nothing but static. The storm must have knocked something out in town. At least the power was still on for now. The rain was still coming down as a dull roar on the roof; blending with the static from the television.

Glancing outside, I saw that it was pitch black from the storm in the night. That made since; I had been out for several hours at this point. I shivered a little and drew the curtains shut as the kettle began to boil. Crash! I didn’t see the lightning, but the thunderclap sounded as if it was right above the house. A few minutes later I returned to the living room, steaming mug in hand. When I returned to the TV, it was still displaying static. (0:57)

As I sipped my tea, there was another clap of thunder and the TV suddenly cut out, plunging the whole room into darkness. Cursing a little, I stumbled my way around the room trying to find the light switch. By the time I go to it, I had stubbed my toe and tripped on several small items I couldn’t see on the floor. I didn’t think I had left anything on the floor before I fell asleep, but the darkness was extremely disorientating. I had probably knocked something over without realizing it when I first woke up.

Click… Click, click, click. Great.

It wasn’t just the TV but the entire power supply was out; probably for most of the town by this point. The rain kept coming down. I could no longer see the white flashes from the lightning but could hear the claps of thunder, much louder than before. I fumbled my way out and down the hall, trying to find the basement door. It was strangely dark.

Despite living here for almost my entire life, the storm seemed to turn the place into somewhere I was unfamiliar with. I wasn’t originally going to try and find a lamp downstairs, but the darkness was oppressive and I had almost dropped my favorite mug trying to find a light switch. I didn’t want to trip on something I couldn’t see and fall. With my luck so far tonight, I would end up stepping on the broken shards and near-boiling tea.

Crash! (1:25)

After what seemed like 30 minutes, I had finally found the basement door. There weren’t any more knickknacks knocked onto the floor, but I couldn’t seem to find anything in the dark. Everything felt like it was in the wrong place. I unlocked and opened the door and began to walk down the stairs, the creaking of the wooden steps being the only nose other than the low roar of the rain and the occasional thunderclap.

Creak, creak, creak…

Were there always so many steps to get to the bottom? When I finally got to the bottom of the stairs the roar of the rain had faded away into nothing. Hopefully the fact that I couldn’t hear the rain down hear meant it was passing by. I began to head in the direction of my emergency lights, annoyed at myself for not getting them out before the storm and for leaving my cell phone upstairs. I figured the cell service would be out, but at least those have a built-in flashlight. That would have made finding the lamps and fuel much quicker and easier. It was then I noticed that something was in the basement. (1:06)

I don’t remember what it looked like or what kind of sounds it made. In fact, I don’t even remember running away. As soon as I encountered it, my body was filled with something I had never experienced before: in an instant I was dripping in a cold sweat, and shaking as my body filled with a unexpected terror. Just a second ago I was hoping the basement hadn’t flooded, but now there was only one thing my brain and body could comprehend, and it was that I needed to run away as fast as possible. In that moment nothing else mattered. If I didn’t move, I knew I was going to die.

When I reached the top of the stairway, I slammed it shut and leaned against it, panting heavily. The roar of the rain was back, but I could tell that it was gradually fading from what it was before I went downstairs. Or maybe it was just my rapid heartbeat blocking out the sound. It was still pitch black in the house, but now I was able to look around and see, maybe my eyes had finally adjusted; maybe my fear had made my pupils dilate more than they were before. I didn’t care, I was just glad to be able to see. Until I looked around. It was the same house I had seen my whole life, but it was… different. (1:15)

I could see that part of the reason it was so dark was that the windows were boarded up. A layer of dust coasted the walls and floor, and that was all that was there. None of the furniture or pictures remained. Shelves were empty, the TV and recliner were no longer in the living room, visible through a half-open door at the end of the hall. I locked the basement door and took a small, caution step forward and immediately winced. I looked down and cursed again. In my rush I had apparently dropped my mug and stepped on one of the pieces; just like I knew would happen. It wasn’t a deep cut and was barely bleeding, but it hurt now that my adrenaline was fading. What had I been so scared of before? (0:43)

I must be extra jumpy from my lack of sleep this week. The basement was mostly just storage, nothing could get in there. I was just about to turn back around to get the lamps again when I felt it: the fear was coming back. I couldn’t remember what the thing in the basement was, just that I had to get away. (0:19)

I could feel that this thing was right behind the door, and that it wanted me. I immediately broke into a sprint to the kitchen window since it was the closest way out of there. I didn’t care where I ended up as long as I was away from here. The pain in my foot was inconsequential now and I ignored it as I ran. I didn’t even notice the small trail of blood following wherever I went. There were no other emotions that fear. I had to escape.

It was no good, the kitchen window was boarded up too tightly to squeeze through. Changing plans, I hurried towards the front door at the oppilate end of the house, making sure to cut through the living room to avoid the basement, but that was also boarded up. I fumbled with the lock, trying to get it open and pry off the boards on the outside. The rain seemed excruciating loud, but I could almost taste safety on the other side of the door.

CRASH! (0:54)

The basement door broke open with a crack much louder than any of the thunder I’d heard so far. Giving up on the door, I immediately ran up the stairs to my left to the second floor. Knowing whatever it was would only be a few moments behind me I wished I had another door to shut to slow it down, if only for a second. As I ran, I could hear the rain on the roof crescendo

All the windows were boarded up, and other than a layer of dust the only thing in any of the main rooms was a large dark stain on the floor of what was my bedroom. It was quickly obvious that I would not find a way out here so I bolted, limping slightly from the pain in my foot. If I could get to the veranda in the back of the house, I might be able to shimmy down the side of the building to safety; assuming I didn’t slip in the rain. It had a glass door after all so I could use my body to break it open. What was a few more scrapes at this point? (1:04)

As I ran, I could feel it getting closer. By this point it was on the second floor with me as I hurried to the door. The closer it got, the more horrified I became. The sound of the rain was almost deafening now, but compared to the entity inside with me, it felt like my salvation. Luckily when I grabbed the veranda door handle, it flew open and I tumbled outside onto the balcony. (0:28)

Outside was pouring rain. The dops fell hard and stung. This constant firing of miniature bullets was painful, but I barely noticed. I needed to find a way out of the house. Out of the neighborhood. Out of the entire town. I was looking around for a drain pipe or a ledge to shimmy across when I noticed it: the view. The trees normally extend through to the hill line below and to the end of my sightline.
They were gone.

The trees weren’t cut down, or replaced by new building, they were just gone. At the end of my backyard the world seemed to just vanish. I couldn’t tell if it was simply too dark to see that far or if my house had been teleported to some other dimension that was pitch black and full of nothing but swirling storm clouds, thunder, and rain. I suppose in the end it didn’t really matter. (0:52)

As I was looking for a way to run away, I could feel it: the same feeling I had in the basement. This terror resonated with me to my core. This was something that felt baked into my very being, something at a baser level than any human logic. Pure, unfiltered fear. I knew that whatever the thing was it was now right behind me on the other side of this last door. I stopped and looked up at the rain. At this moment the rain suddenly let up. I could see the stars through the eye of the storm and as the sound of the raindrops stopped, only to be replaced by the crashing of the veranda door being knocked open. (0:53)

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

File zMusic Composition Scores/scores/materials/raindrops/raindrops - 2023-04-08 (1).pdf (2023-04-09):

# Raindrops on a Tin Roof

# for Cyberinet, pre-recorded sounds, and live electronics

# Matthew A. Bardin

2023


Program Note:
A short story. An event. When you are the most comfortable, that is when the unknown can strike. Usually in a way we least expect. How can one respond to the uncomprehendable?
Approximately 12-15 minutes in duration. Completed March 15

th 2023 in Baton Rouge, LA MaB

Performance Notes:
For the Performance of Raindrops on a Tin Roof, a unique setup can be utilized. The theatrical stage setup is not required, but highly encouraged by the composer if possible as they enhance the atmosphere.

The performer should arrange three stands across the width of the stage. When instructed in the score, the performer should move from their current stand to the indicated stand. A smoke machine should be placed upstage and off-center of the performer to minimize its visibility from the audience. The smoke machine should be set to approximately medium-low. There should be a low mist/fog that picks up the lights in the room, not so much that it becomes obstructive.Two DMX-controlled lights should be placed slightly downstage of the performer, illuminating the stage. Stage lights should be turned off, but if needed spotlights, stand lights, or low-level lighting can be used to illuminate the three stands for the performer. Will all of the staging, the performance space should look like this:

Smoke Machine

3 | 1 | 2
Light | Light
| Audience

The following Performance Pages should be on the stands as shown below:

1. Pgs 1-2, 4-5, 9-10
2. Pgs 5-8
3. Pgs 2-4

Multiple stands at some stanf locations may be needed.

Adjustments to the staging can be made depending on the specifics of the performance venue. The atmosphere should be spooky, and as if rain will begin at any second. A fan is recommended to help dissipate the smoke following the performance.

Tempo markings should be observed as close as possible. Tempi indicated are those of the synthesizer accompaniment sound files. When the “as fast as possible” instruction occurs, the performer should play the section as fast as possible while still maintaining rhythmic and pitch integrity. Do not worry about playing in time with the synthesizer during these moments. There will be a moment to return to being in time with the synthesizer indicated with the button.

On Software:
The Raindrops on a Tin Roof Max Patch is required for the performance. This patch can be downloaded from matthewbardin.com/raindrops. If needed, Max (Version 8.5 or newer needed) can be downloaded from cycling74.com. It is not required to purchase the software as the patch will run in demo mode, however it is recommended if possible as purchasing the software will unlock editing and saving of patches.

The Max patch will take data from the Cyberinet’s embedded sensors and use them to process sounds as shown below:

Gyroscope: Used to control reverb and panning Accelerometer: Used to control DMX Lights, playback volume, and delay Airflow: Used to control DMX Lights, playback volume, and distortion Button 1: Used to cycle through settings and trigger audio clips Button 2: Emergency Mute All switch

Largely speaking, the Cyberinet controls the volume of various sound files on playback, as well as the processing to those sound files. The clarinet timbre is the only element with no processing applied to it.

There are three categories of sound files used in Raindrops on a Tin Roof:

1. Synthesizer Accompaniment: Unnatural, distorted sounds to accompany the clarinet timbres.
2. Ambiance: Digetic sounds occurring in the story as it unfolds. These include rain sounds, monster sounds, and creaking floorboards
3. Narrator: Recordings of the composer reading the story. These are used to provide context to the music as it is happening. Generally the music pauses during these moments.

On Hardware:
The performer will need the Cyberinet as well as the button expansion to perform Raindrops on a Tin Roof. In addition to the items listed under ‘Performance Notes’, The performer will require a computer to run the software patch. This computer can be either Windows or MacOS. The software patch will run on either devices. A USB-to-DMX adapter for each of the lights are also needed as they will be controlled from the max patch.

On Notation:
Cross Noteheads: Indicate pressing Button 1 to progress to the following section of music.

Vamp: Repeat the indicated music as many times as wanted or needed. Each vamp should occur at least 3 times. All other repeats occur once.
Travel Instructions: Tell the performer their method of moving from one stand to another. This text is always underlined.

Movement Indicators: Indicate exaggerated movements or breathing.
Exaggerated movements should generally be swaying or small steps to trigger the gyroscope more.

Exaggerate breathing should be heavier and more frequent breaths than normal in order to further trigger the airflow sensor. Take care not to hyperventilate.

Synthesizer parts: Are not intended to be performed by a person. The part present in the score is the notation of the accompanying sound file. This notation does not reflect the specific processing applied to the sounds as that will change with each performance, but general indications are given to help the performer stay in time with the accompaniment.

Narrator Text: Text indicators for the narrator files are printed in the score. The first and last line are printed; separated with an ellipsis (...). The duration of the file is also provided. This text is always boxed and italicized.

Metric Relations: eighth notes are constant throughout whenever a time signature change occurs.

Print Versions of the score arrive hole punched for storage, but are kept loose for arrangement on the stands. Extra copies of necessary pages are provided.

Narration Full Text:

White flash… 9,10,11… crash!

The storm outside was gradually drawing closer. I lay back in my recliner and sipped my tea. The smell of mint combined with the warmth of the fireplace nearby was soothing. After this past week at work, I was looking forward to relaxing. Another flash of light. …7,8…crash!

This storm was oddly out of season, but not unheard of. At most a few trees get blown over and knock out the power, maybe a little flooding in the lower areas of town, but nothing that isn’t resolved and forgotten within a few days.

I sat there, sipping my tea, enjoying the solitude and relative silence of the house. It was around this time that the sound of the rain began to reach me. The sound grew so gradually that I have no idea when it really started, but by the time I had finished my tea and the final chapter of my novel, the sound, filtered through two floors of family history passed down along with the house, the sound had developed into a dull roar of water droplets on my house’s metal roof. It was constant, yet soothing. Maybe the storm would be a quick one. The floorboards creaked as I walked over to the window.

4,5,6,7…

The timing between the lighting and thunder was getting closer and closer. Hopefully this would move past without too much trouble, but it didn’t seem to be moving any faster than before. (1:32)

I decided to take a break from reading and turned on the TV instead. Flash… 3,4,5… crash!

The thunder had startled me awake, and I was both a little groggy and confused that I had fallen asleep so unexpectedly. The long days at work must have worn me out more than I originally thought. The TV was displaying nothing but static. The storm must have knocked something out in town. At least the power was still on for now. The rain was still coming down as a dull roar on the roof; blending with the static from the television.

Glancing outside, I saw that it was pitch black from the storm in the night. That made since; I had been out for several hours at this point. I shivered a little and drew the curtains shut as the kettle began to boil. Crash! I didn’t see the lightning, but the thunderclap sounded as if it was right above the house. A few minutes later I returned to the living room, steaming mug in hand. When I returned to the TV, it was still displaying static. (0:57)

As I sipped my tea, there was another clap of thunder and the TV suddenly cut out, plunging the whole room into darkness. Cursing a little, I stumbled my way around the room trying to find the light switch. By the time I go to it, I had stubbed my toe and tripped on several small items I couldn’t see on the floor. I didn’t think I had left anything on the floor before I fell asleep, but the darkness was extremely disorientating. I had probably knocked something over without realizing it when I first woke up.

Click… Click, click, click. Great.

It wasn’t just the TV but the entire power supply was out; probably for most of the town by this point. The rain kept coming down. I could no longer see the white flashes from the lightning but could hear the claps of thunder, much louder than before. I fumbled my way out and down the hall, trying to find the basement door. It was strangely dark.

Despite living here for almost my entire life, the storm seemed to turn the place into somewhere I was unfamiliar with. I wasn’t originally going to try and find a lamp downstairs, but the darkness was oppressive and I had almost dropped my favorite mug trying to find a light switch. I didn’t want to trip on something I couldn’t see and fall. With my luck so far tonight, I would end up stepping on the broken shards and near-boiling tea.

Crash! (1:25)

After what seemed like 30 minutes, I had finally found the basement door. There weren’t any more knickknacks knocked onto the floor, but I couldn’t seem to find anything in the dark. Everything felt like it was in the wrong place. I unlocked and opened the door and began to walk down the stairs, the creaking of the wooden steps being the only nose other than the low roar of the rain and the occasional thunderclap.

Creak, creak, creak…

Were there always so many steps to get to the bottom? When I finally got to the bottom of the stairs the roar of the rain had faded away into nothing. Hopefully the fact that I couldn’t hear the rain down hear meant it was passing by. I began to head in the direction of my emergency lights, annoyed at myself for not getting them out before the storm and for leaving my cell phone upstairs. I figured the cell service would be out, but at least those have a built-in flashlight. That would have made finding the lamps and fuel much quicker and easier. It was then I noticed that something was in the basement. (1:06)

I don’t remember what it looked like or what kind of sounds it made. In fact, I don’t even remember running away. As soon as I encountered it, my body was filled with something I had never experienced before: in an instant I was dripping in a cold sweat, and shaking as my body filled with a unexpected terror. Just a second ago I was hoping the basement hadn’t flooded, but now there was only one thing my brain and body could comprehend, and it was that I needed to run away as fast as possible. In that moment nothing else mattered. If I didn’t move, I knew I was going to die.

When I reached the top of the stairway, I slammed it shut and leaned against it, panting heavily. The roar of the rain was back, but I could tell that it was gradually fading from what it was before I went downstairs. Or maybe it was just my rapid heartbeat blocking out the sound. It was still pitch black in the house, but now I was able to look around and see, maybe my eyes had finally adjusted; maybe my fear had made my pupils dilate more than they were before. I didn’t care, I was just glad to be able to see. Until I looked around. It was the same house I had seen my whole life, but it was… different. (1:15)
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

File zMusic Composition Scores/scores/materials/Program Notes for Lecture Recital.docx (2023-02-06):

Program Notes for Lecture Recital:

Puzzle of a Park:

Ethereal Presence:

Raindrops on a Tin Roof:

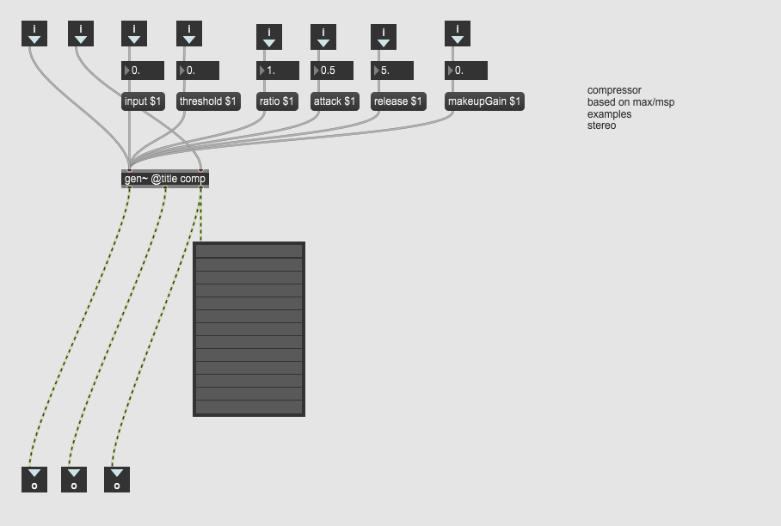
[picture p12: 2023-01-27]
zMusic Composition Scores/performances/Lecture Recital/Bardin Lecture Recital Materials/compressorA.png

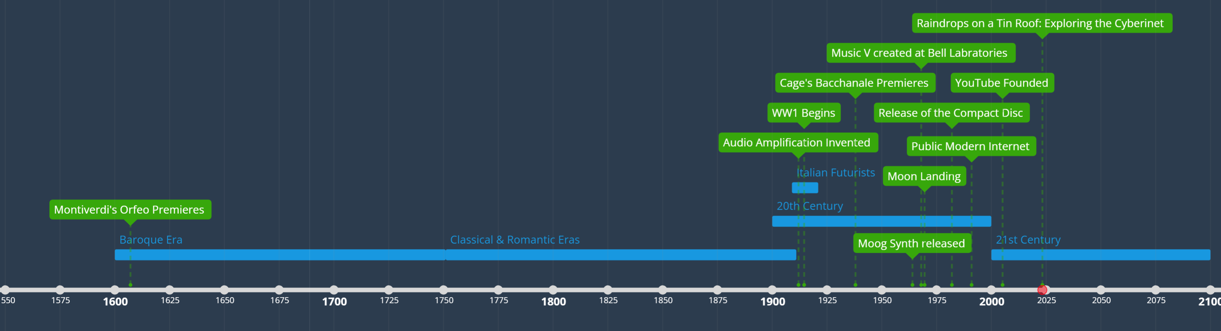
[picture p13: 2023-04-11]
zMusic Composition Scores/performances/Lecture Recital/Bardin Lecture Recital Materials/timeline.png

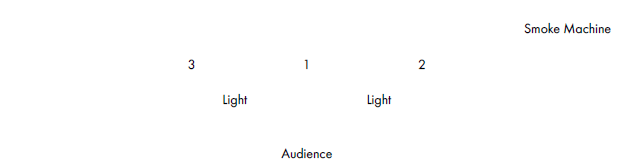
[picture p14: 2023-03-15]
zMusic Composition Scores/scores/materials/raindrops/planning diagrams/screenshots/stage.png

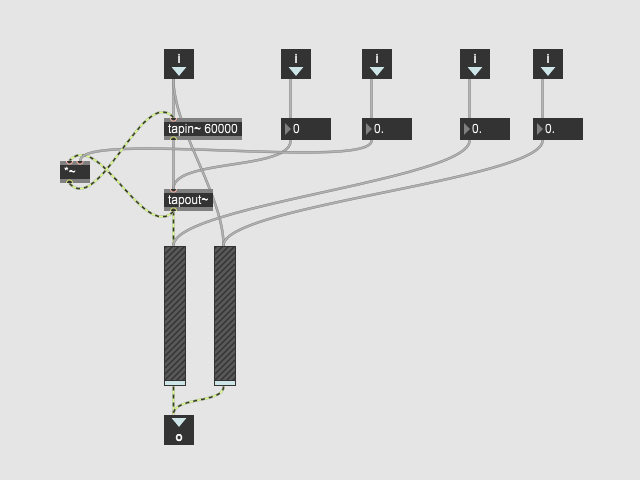
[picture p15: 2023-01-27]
zMusic Composition Scores/performances/Lecture Recital/Bardin Lecture Recital Materials/feedbackDelay.png

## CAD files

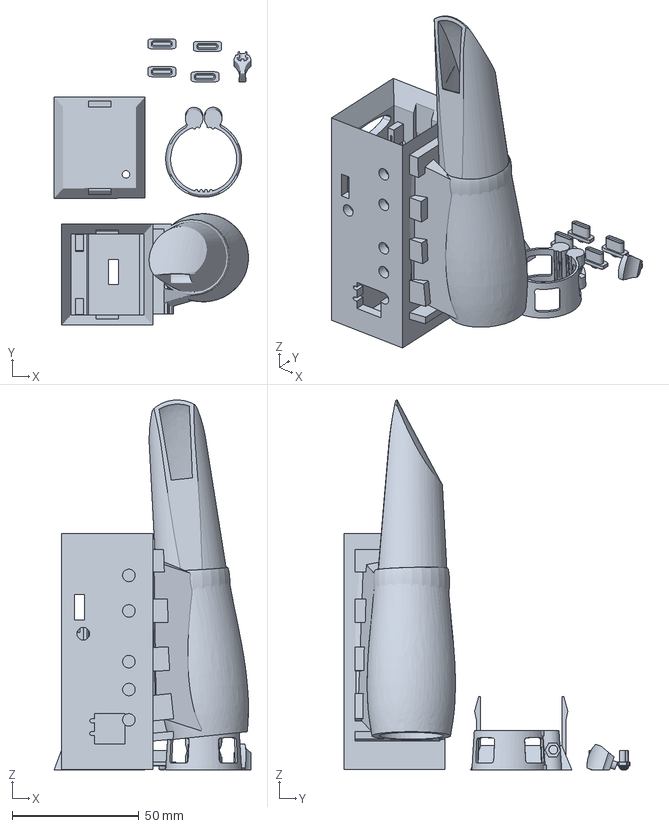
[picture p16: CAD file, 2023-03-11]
V1.3/3DPrint/drafts/3dModel/V1 box Full.3mf
77.6 x 113.0 x 146.0 mm

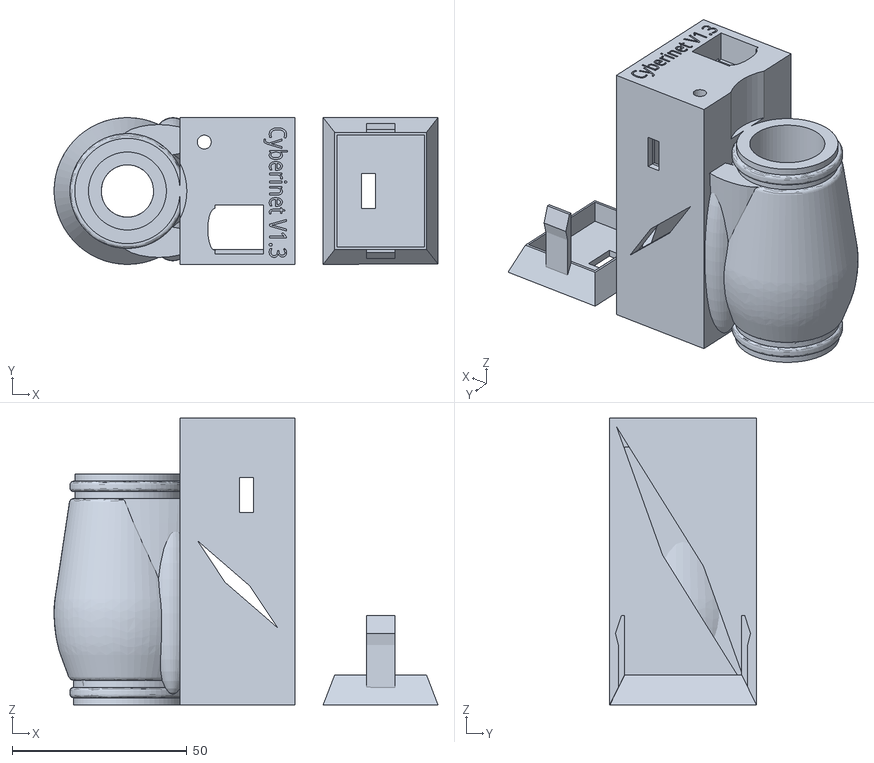
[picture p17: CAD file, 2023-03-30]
V1.3/3DPrint/drafts/Cyberinet main Box (3).stl
109.9 x 42.0 x 82.0

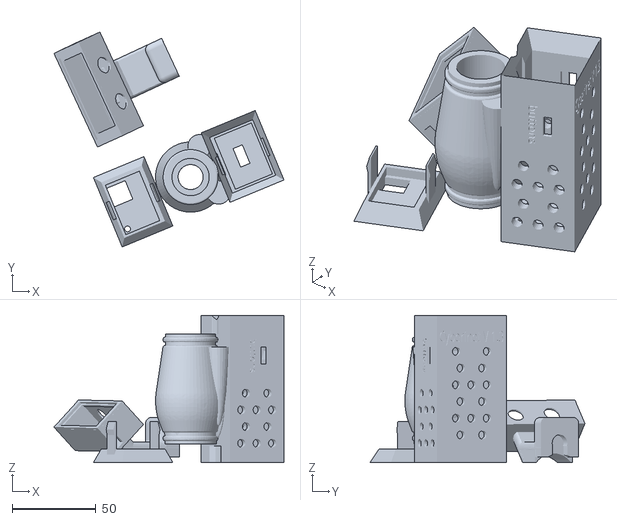
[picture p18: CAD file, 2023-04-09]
V1.3/3DPrint/drafts/cyberinetV1.3finalIHope.stl
137.7 x 128.7 x 88.0

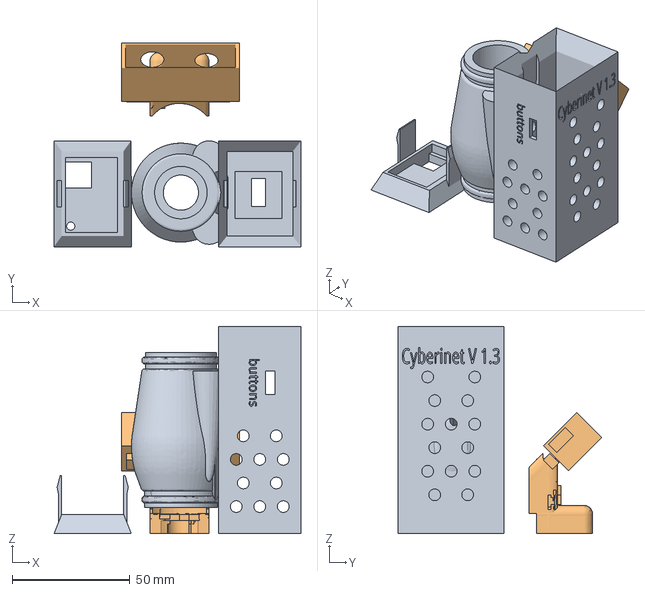
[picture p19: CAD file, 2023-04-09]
V1.3/3DPrint/drafts/SlicedFiles/box 1.3 take2.3mf
104.9 x 86.4 x 88.0 mm
box 1.3 take2.stl
tinker.obj

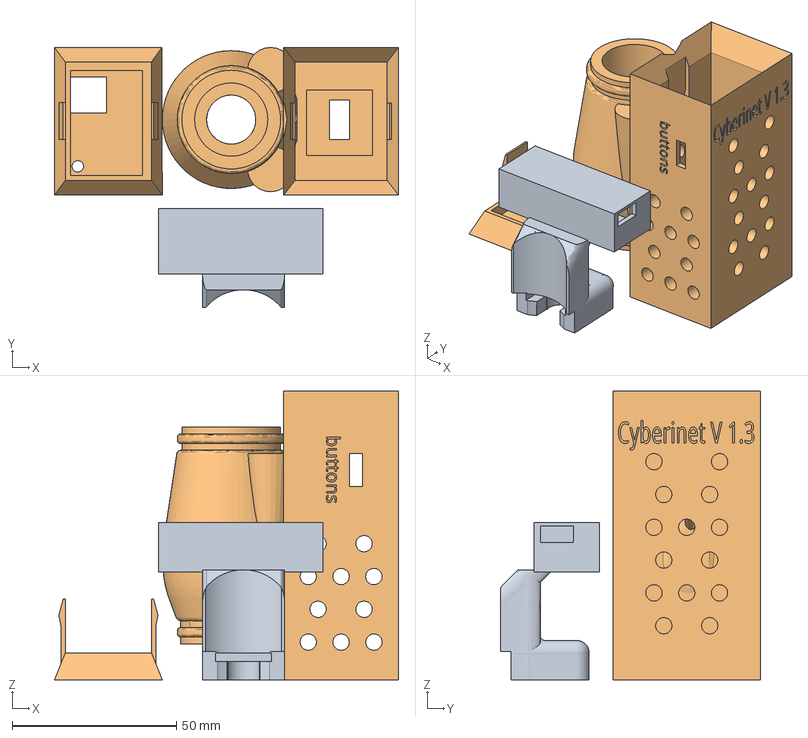
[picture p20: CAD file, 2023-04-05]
V1.3/3DPrint/drafts/box box box.3mf
104.9 x 79.3 x 88.0 mm
Thumbrest (2).stl
box 1.3 take2.stl

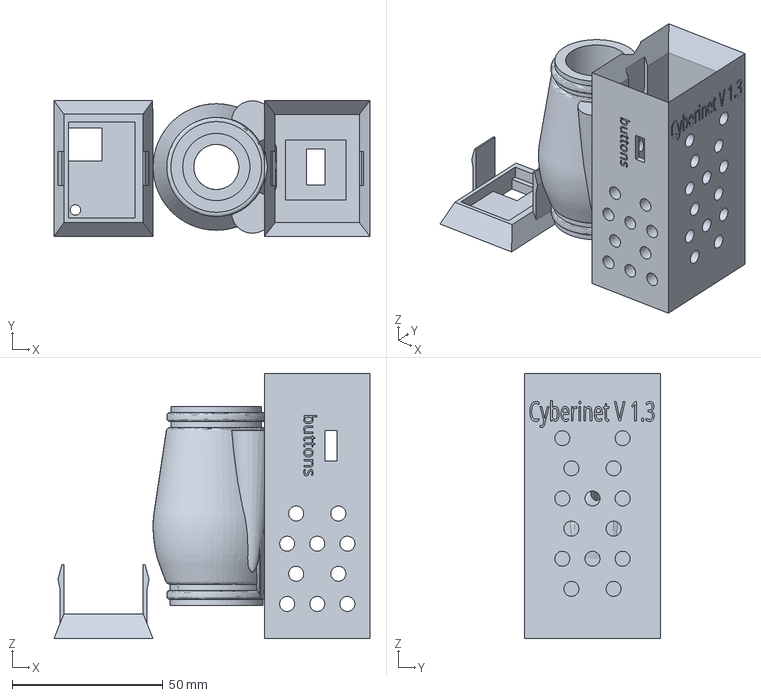
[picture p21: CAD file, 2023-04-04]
V1.3/3DPrint/drafts/box 1.3 take2.3mf
104.9 x 45.0 x 88.0 mm

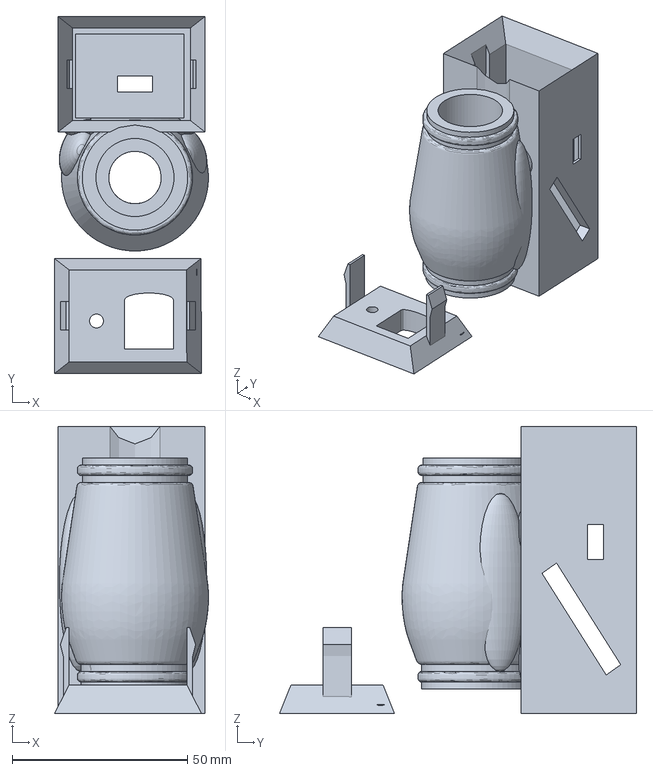
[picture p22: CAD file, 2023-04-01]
V1.3/3DPrint/drafts/Cyberinet v 1.3Final Draft PLA.3mf
44.0 x 102.0 x 82.0 mm

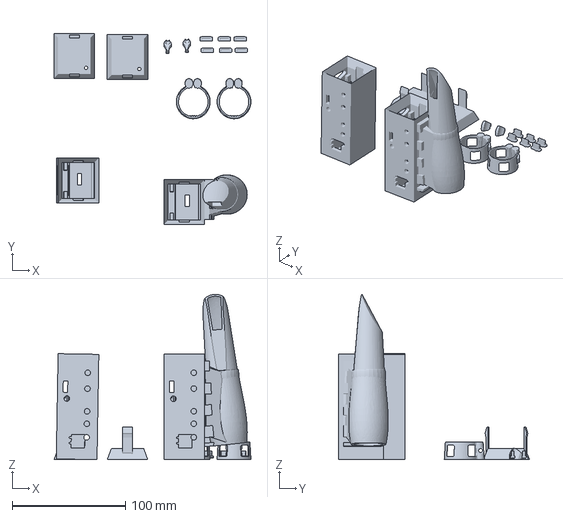
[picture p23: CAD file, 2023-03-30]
V1.3/3DPrint/drafts/V1 box TEST.3mf
174.0 x 169.0 x 146.0 mm

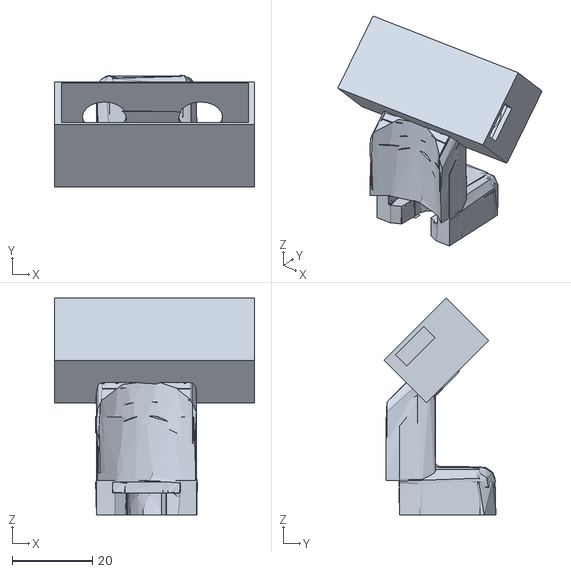
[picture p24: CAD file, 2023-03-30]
V1.3/3DPrint/drafts/button rest (1).stl
50.0 x 27.9 x 54.2

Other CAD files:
V1.3/3DPrint/drafts/SlicedFiles/V1 box Full close 1.3mf
V1.3/3DPrint/drafts/box try number i lost count.stl
V1.3/3DPrint/drafts/3dModel/V1 box Full.stl
V1.3/3DPrint/drafts/box 1.3 take2.stl

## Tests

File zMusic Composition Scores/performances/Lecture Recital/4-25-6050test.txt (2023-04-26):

3, -5.14 -0.04 -1.37 0.9 0.49 -0.09;
4, -3.01 0.65 -1.69 0.9 0.46 -0.1;
5, -4.5 1.63 1.21 0.87 0.53 -0.1;
6, -4.17 0.21 -1.18 0.87 0.54 -0.17;
7, -4.95 -2.31 -3.1 -0.04 0.94 -0.34;
8, -5.57 -1.69 -0.28 0.97 0.35 -0.11;
9, -4.02 -0.05 -5.39 0.81 0.61 -0.16;
10, 8.16 4.6 0.68 0.75 0.67 -0.17;
11, -3.82 1.25 -5.34 0.78 0.64 -0.1;
12, -2.48 -0.77 -3.54 0.75 0.65 -0.25;
13, -7.91 -2.95 -1.92 0.75 0.66 -0.07;
14, -4.87 1.47 -5.58 0.79 0.59 -0.3;
15, -8.06 -4.6 -1.52 0.85 0.55 -0.18;
16, -0.41 -2.22 0.47 0.5 -0.87 0.13;
17, -217.59 -8.65 -38.99 0.92 -0.27 0.13;
18, 29.11 -0.69 14.64 0.91 -0.4 -0.07;

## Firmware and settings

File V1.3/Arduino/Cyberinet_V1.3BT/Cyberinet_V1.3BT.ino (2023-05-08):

/*
    Micro Controller Code for the Cyberinet Version 1.3
   Code designed for the ESP-32 WROOM DEVKIT V1 in the Arduino IDE.
   All Serial Communications are over Bluetooth.
   Code may be used or reworked with Attribution. Altering code present on Cyberinet unit is not recommended.
   Code and Other Matierials for the Cyberinet can be found at https://github.com/mbardin/Cyberinet
   Code and Other Marerials made by Matthew A. Bardin [2023] (https://matthewbardin.com)
*/

//libraries to include
#include <SparkFun_SDP3x_Arduino_Library.h>
#include<Wire.h>
#include <BluetoothSerial.h>
#include <MPU6050.h>


// create instances of the libraries above
BluetoothSerial SerialBT;
MPU6050 mpu;
SDP3X airFlow; // constant sensing is on I2C address 0x21


// Global Variables
// dedicated pins
const int pwrLED = 2; // green 330 Ohm
const int msgLED = 4; // red 220 Ohm
const int button1 = 12;
const int button2 = 14;
const int b1LED = 26;
const int b2LED = 27;
const int expPin1 = 33;
const int expPin2 = 32;
const int expPin3 = 35;
const int expPin4 = 18;

// MPU 6050 values
const int MPU_ADDR = 0x68; // I2C address of the MPU-6050
int16_t AcX, AcY, AcZ, GyX, GyY, GyZ; // values for 6050
float rotX, rotY, rotZ, gForceX, gForceY, gForceZ; // store mapped values for transmitting

// stores current button state
int button1State = 1;
int button2State = 1;

// store SDP31 values for transmitting
//float diffPressure = 0.0;
//float temperature = 0.0;

void setup() {
  // Pin mode assignment
  pinMode(pwrLED, OUTPUT);
  pinMode(msgLED, OUTPUT);
  pinMode(button1, INPUT_PULLUP); // use ESP32's built in pullup resistors
  pinMode(button2, INPUT_PULLUP);

  Serial.begin(115200);
  SerialBT.begin("CyberinetV13"); // Device name. no spaces or punctuation
  delay(1000); // pause before checking
  // various startup and checks
  gyroStartup();
  airflowStartup();
  // device must be restarted if optional expansions are added
  // if everything clears
  startLights();
}



void loop() { // check the sensors and transmit each loop.
  get6050();
  getButtons();
  getExp();
  getAir(); // put 6050 and sdp31 on ends of sensor checks
}


void get6050() {

  ////////////Collect Data
  Wire.beginTransmission(MPU_ADDR);
  Wire.write(0x3B);  // wake up device
  Wire.endTransmission(true);

  Wire.requestFrom(MPU_ADDR, 6); //Request Accel Registers (3B - 40)
  while (Wire.available() < 6);
  AcX = Wire.read() << 8 | Wire.read(); // operator first bitshifts the sensor value by 8 bits,
  AcY = Wire.read() << 8 | Wire.read(); // then does a bitwise OR to compare to raw data
  AcZ = Wire.read() << 8 | Wire.read(); // enbd result is a combined original and bitshift

  Wire.beginTransmission(MPU_ADDR); //I2C address of the MPU
  Wire.write(0x43); //Starting register for Gyro Readings
  Wire.endTransmission();
  Wire.requestFrom(MPU_ADDR, 6); //Request Gyro/Accel Registers (43 - 48)
  while (Wire.available() < 6);
  GyX = Wire.read() << 8 | Wire.read();
  GyY = Wire.read() << 8 | Wire.read();
  GyZ = Wire.read() << 8 | Wire.read();


  ////////////Format Data
  rotX = GyX *  0.007633587786; // gravity and rotation offsets
  rotY = GyY *  0.007633587786;
  rotZ = GyZ *  0.007633587786;

  gForceX = AcX * 0.00006103515;
  gForceY = AcY * 0.00006103515;
  gForceZ = AcZ * 0.00006103515;


  ////////////Transmit Data
  digitalWrite(msgLED, HIGH); // turn on LED when when transmitting
  SerialBT.print("gyroX "); // label
  SerialBT.println(rotX); // value

  SerialBT.print("gyroY "); // label
  SerialBT.println(rotY); // value

  SerialBT.print("gyroZ "); // etc.
  SerialBT.println(rotZ);

  SerialBT.print("accelX ");
  SerialBT.println(gForceX);

  SerialBT.print("accelY ");
  SerialBT.println(gForceY);

  SerialBT.print("accelZ ");
  SerialBT.println(gForceZ);
  digitalWrite(msgLED, LOW);// turn off led when done transmitting
}

void getButtons() {
  ////////////Collect Data
  button1State = digitalRead(button1);
  button2State = digitalRead(button2);

  ////////////Transmit Data (every frame. CNET.receive Max Object filters out repetitions.)
  digitalWrite(msgLED, HIGH); // turn LED on when tranmitting data
  SerialBT.print("b1 "); // label
  SerialBT.println(button1State); // value
  digitalWrite(b1LED, button1State); // on-board led state matches button state
  // repeat for other button
  SerialBT.print("b2 ");
  SerialBT.println(button2State);
  digitalWrite(b1LED, button2State);
  digitalWrite(msgLED, LOW); // turn off led when done transmitting
}

int exp1State = 0;
int exp2State = 0;
int exp3State = 0;
int exp4State = 0;

void getExp() {
  // Look at each return pin
  exp1State = digitalRead(expPin1);
  exp2State = digitalRead(expPin2);
  exp3State = digitalRead(expPin3);
  exp4State = digitalRead(expPin4);

  // transmitData
  digitalWrite(msgLED, HIGH);
  SerialBT.print("exp1 ");
  SerialBT.println(exp1State);
  SerialBT.print("exp2 ");
  SerialBT.println(exp2State);
  SerialBT.print("exp3 ");
  SerialBT.println(exp3State);
  SerialBT.print("exp4 ");
  SerialBT.println(exp4State);
  digitalWrite(msgLED, LOW);
}

void getAir() {
  ////////////Collect Data

  float diffPressure; // Storage for the differential pressure
  float temperature; // Storage for the temperature
  airFlow.readMeasurement(&diffPressure, &temperature);

  ////////////Transmit Data
  digitalWrite(msgLED, HIGH); // turn on LED when tranmitting
  SerialBT.print(F("airP ")); // lebel
  SerialBT.println(diffPressure, 2); // value

  SerialBT.print(F("temp "));
  SerialBT.println(temperature, 2);
  digitalWrite(msgLED, LOW); // turn of LED when done transmitting
}


// startup functions
void gyroStartup() {
  Wire.begin(21, 22, 100000); // sda, scl, clock speed
  Wire.beginTransmission(MPU_ADDR);
  Wire.write(0x6B);  // PWR_MGMT_1 register
  Wire.write(0);     // (wakes up the MPU−6050)
  Wire.endTransmission(true);
  SerialBT.println("MPU-6050 Setup Complete");
}

void airflowStartup() {
  // Initialize sensor. Stops if connection cannot be made
  airFlow.stopContinuousMeasurement();

  if (airFlow.begin() == false)
  {
    SerialBT.println(F("SDP31 not detected. Check connections. Freezing..."));
    while (1);
  }

  airFlow.startContinuousMeasurement(true, true); // set to continuous measurement mode
  SerialBT.println("SDP31 Setup Complete");
}

void startLights() { // flashes startup LED in apecific pattern
  // process takes 3.5 seconds
  digitalWrite(pwrLED, HIGH);
  digitalWrite(msgLED, HIGH);
  delay(500);
  digitalWrite(msgLED, LOW);
  delay(500);
  digitalWrite(msgLED, HIGH);
  delay(500);
  digitalWrite(msgLED, LOW);
  delay(1000);
  digitalWrite(msgLED, HIGH);
  delay(1000);
  digitalWrite(msgLED, LOW); // turns off LED so it can be activated when tranmitting.
}

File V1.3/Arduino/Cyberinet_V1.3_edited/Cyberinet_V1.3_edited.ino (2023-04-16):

//libraries to include
#include <SparkFun_SDP3x_Arduino_Library.h>
#include<Wire.h>
#include <BluetoothSerial.h>
//#include <MPU6050.h>



// create instances of the libraries above
BluetoothSerial SerialBT;
//MPU6050 mpu;
SDP3X airFlow; // constant sensing is on I2C address 0x21


// Global Variables
// dedicated pins
const int pwrLED = 2; // green 330 Ohm
const int msgLED = 4; // red 220 Ohm
const int button1 = 12;
const int button2 = 14;
const int b1LED = 26;
const int b2LED = 27;

const int MPU_ADDR = 0x68; // I2C address of the MPU-6050
int16_t AcX, AcY, AcZ, GyX, GyY, GyZ, Tmp; // values for 6050

// pValues are previously sensed values. Used to reduce noise in signal.

int button1State = 0;
int button2State = 0;

float rotX, rotY, rotZ, gForceX, gForceY, gForceZ; //pDiff, pTemp
float diffPressure = 0.0;
float temperature = 0.0;
int error = 6;
void setup() {
  // Pin mode assignment
  pinMode(pwrLED, OUTPUT);
  pinMode(msgLED, OUTPUT);
  pinMode(button1, INPUT_PULLUP); // use ESP32's built in pullup resistors
  pinMode(button2, INPUT_PULLUP);
  Serial.begin(115200); // making sure this is before serialBT.begin ?
  //SerialBT.begin("Cyberinet V.1.3"); // Device name that will appear on computer
  Wire.begin(21, 22, 400000); // sda, scl, clock speed
  Wire.beginTransmission(MPU_ADDR);
  Wire.write(0x6B);  // PWR_MGMT_1 register
  Wire.write(0);     // (wakes up the MPU−6050)
  error = Wire.endTransmission(true);
  Serial.println(error);
  //  if (error == 0) {
  //    Serial.println("6050 Setup Complete");
  //  } else if (error != 2) {
  //    Serial.println("Error");
  //  }
  delay(1000); // pause before checking
  //gyroStartup();
  //airflowStartup();
  // device must be restarted if optional expansions are added
  // expansionCheck(); // make function to chekc for additoinal expansions in future versions
  // if everything clears
  //startLights();
}

void loop() { // check the sensors and transmit each loop.
 // get6050();
////////////////////
Wire.beginTransmission(MPU_ADDR);
  Wire.write(0x3B);  // starting with register 0x3B (ACCEL_XOUT_H)
  Wire.endTransmission(true);
  Wire.beginTransmission(MPU_ADDR);
  Wire.requestFrom(MPU_ADDR, 14, true); // request a total of 14 registers
  AcX = Wire.read() << 8 | Wire.read(); // 0x3B (ACCEL_XOUT_H) & 0x3C (ACCEL_XOUT_L)
  AcY = Wire.read() << 8 | Wire.read(); // 0x3D (ACCEL_YOUT_H) & 0x3E (ACCEL_YOUT_L)
  AcZ = Wire.read() << 8 | Wire.read(); // 0x3F (ACCEL_ZOUT_H) & 0x40 (ACCEL_ZOUT_L)
  Tmp = Wire.read() << 8 | Wire.read(); // 0x41 (TEMP_OUT_H) & 0x42 (TEMP_OUT_L)
  GyX = Wire.read() << 8 | Wire.read(); // 0x3B (ACCEL_XOUT_H) & 0x3C (ACCEL_XOUT_L)
  GyY = Wire.read() << 8 | Wire.read(); // 0x3D (ACCEL_YOUT_H) & 0x3E (ACCEL_YOUT_L)
  GyZ = Wire.read() << 8 | Wire.read(); // 0x3F (ACCEL_ZOUT_H) & 0x40 (ACCEL_ZOUT_L)


  Serial.print(AcX); Serial.print(" , ");
  Serial.print(AcY); Serial.print(" , ");
  Serial.print(AcZ); Serial.print(" , ");
  Serial.print(GyX); Serial.print(" , ");
  Serial.print(GyY); Serial.print(" , ");
  Serial.print(GyZ); Serial.print("\n");





//////////////////
 
  //getButtons();
 // getAir(); // put 6050 and sdp31 on ends of sensor checks to give time between accessing the I2C pin.
}


void get6050() {
  Serial.println("test1");
  Wire.beginTransmission(MPU_ADDR);
  Wire.write(0x3B);  // starting with register 0x3B (ACCEL_XOUT_H)
  Wire.endTransmission(true);

  Serial.println("test2");

  Wire.requestFrom(MPU_ADDR, 6, true); //Request Accel Registers (3B - 40)
  while (Wire.available() < 6);
  AcX = Wire.read() << 8 | Wire.read();
  AcY = Wire.read() << 8 | Wire.read();
  AcZ = Wire.read() << 8 | Wire.read();


  Serial.println("test3");
  Wire.beginTransmission(MPU_ADDR); //I2C address of the MPU
  Wire.write(0x43); //Starting register for Gyro Readings


  Serial.println("test4");
  Wire.requestFrom(MPU_ADDR, 6, true); //Request Gyro Registers (43 - 48)
  while (Wire.available() < 6);
  GyX = Wire.read() << 8 | Wire.read();
  GyY = Wire.read() << 8 | Wire.read();
  GyZ = Wire.read() << 8 | Wire.read();


  Serial.println("test5");
  rotX = GyX *  0.007633587786; // mult is better for computations
  rotY = GyY *  0.007633587786;
  rotZ = GyZ *  0.007633587786;
  Serial.println("test6");
  gForceX = AcX * 0.00006103515;
  gForceY = AcY * 0.00006103515;
  gForceZ = AcZ * 0.00006103515;
  Serial.println("test7");
  digitalWrite(msgLED, HIGH);
  Serial.print("GyroX ");
  Serial.println(rotX);

  Serial.print("GyroY ");
  Serial.println(rotY);

  Serial.print("GyroZ ");
  Serial.println(rotZ);
  digitalWrite(msgLED, LOW);

  digitalWrite(msgLED, HIGH);
  Serial.print("AcelX ");
  Serial.println(gForceX);

  Serial.print("AclY ");
  Serial.println(gForceY);

  Serial.print("AcelZ ");
  Serial.println(gForceZ);
  digitalWrite(msgLED, LOW);
}

void getButtons() { // currently whenever pressed. look into holding and release options
  button1State = digitalRead(button1);
  button2State = digitalRead(button2);

  digitalWrite(msgLED, HIGH);
  // transmit  values and change LED when the button changes state
  Serial.print("Button1 ");
  Serial.println(button1State);
  digitalWrite(b1LED, button1State);
  digitalWrite(msgLED, LOW);

  // buttons are independant of each other
  digitalWrite(msgLED, HIGH);
  Serial.print("Button2 ");
  Serial.println(button2State);
  digitalWrite(b1LED, button2State);
  digitalWrite(msgLED, LOW);
}

void getAir() {
  // store previous values
  airFlow.readMeasurement(&diffPressure, &temperature); // get values

  digitalWrite(msgLED, HIGH);

  Serial.print(F("AirP "));
  Serial.println(diffPressure, 2);

  digitalWrite(msgLED, LOW);

  digitalWrite(msgLED, HIGH);
  Serial.print(F("Temp "));
  Serial.println(temperature, 2);
  digitalWrite(msgLED, LOW);
}

// startup functions
void gyroStartup() {
  Wire.beginTransmission(MPU_ADDR);
  Wire.write(0x6B);  // PWR_MGMT_1 register
  Wire.write(0);     // (wakes up the MPU−6050)
  error = Wire.endTransmission(true);
  Serial.println(error);
  //  if (error == 0) {
  //    Serial.println("6050 Setup Complete");
  //  } else if (error != 2) {
  //    Serial.println("Error");
  //  }
}

void airflowStartup() {
  // Initialize sensor
  //  Wire.begin(21, 22, 100000);
  airFlow.stopContinuousMeasurement();
  if (airFlow.begin() == false)
  {
    Serial.println(F("SDP31 not detected. Check connections. Freezing..."));
    while (1);
  }

  airFlow.startContinuousMeasurement(true, true);
  // Serial.println("SDP31 Setup Complete");
}

void startLights() { // flashes startup LED in apecific pattern
  digitalWrite(pwrLED, HIGH);
  digitalWrite(msgLED, HIGH);
  delay(500);
  digitalWrite(msgLED, LOW);
  delay(500);
  digitalWrite(msgLED, HIGH);
  delay(500);
  digitalWrite(msgLED, LOW);
  delay(500);
  digitalWrite(msgLED, HIGH);
  delay(1000);
  digitalWrite(msgLED, LOW);
}

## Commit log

2022-11-12 Initial Commit
    Adding .ino code, PCBs, and in-progress Max patches
    [Main Boardv1.1_contour.gm1, Main Boardv1.1_copperBottom.gbl, Main Boardv1.1_copperTop.gtl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]
2022-11-29 Working on composition 1 materials
2023-01-24 made a filter
2023-01-29 adding materials and plans for raindrops
2023-02-07 adding draft of 3d case
    [Main Boardv1.1_contour.gm1, Main Boardv1.1_copperBottom.gbl, Main Boardv1.1_copperTop.gtl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]
2023-02-07 add preface material to Puzzle score
2023-02-10 updated and sliced current 3d model
    [V1 box Full.3mf, V1 box Full.stl, V1.1BoxFull.stl]
2023-02-22 Create raindrops - Flow 1 Synthesizer.mp3
2023-02-25 cut up synth accompany files for use in max patch
2023-03-08 binary updates for new 3d models
    [V1 box Full.3mf]
2023-03-11 Create V1 box Full close 1.3mf
    [V1 box Full close 1.3mf]
2023-03-17 updating PCB diagrams
    [Main Boardv1.1_contour.gm1, Main Boardv1.1_copperBottom.gbl, Main Boardv1.1_copperTop.gtl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]
2023-03-17 exporting PCB files for production
2023-03-19 Create Cyberinet_V1.3.1.ino
    testing a new version for new boards
2023-03-28 updating arduino. Next step enabling BT.
    turn on SerialBT functions in Arduino Code
2023-03-30 added current draft of 3D models
    [Cyberinet main Box (3).stl, button rest (1).stl]
2023-03-30 added drafts of 3d prints
    [V1 box TEST.3mf]
2023-04-01 3d print final draft (main unit)
    [Cyberinet v 1.3Final Draft PLA.3mf]
2023-04-02 Update cyberinet spring 2023.pptx
2023-04-04 redid 3d print. last was slightly too small
    [box 1.3 take2.stl]
2023-04-04 organizing a few file locations
    [Cyberinet main Box (3).stl, Cyberinet v 1.3Final Draft PLA.3mf, box 1.3 take2.stl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]
2023-04-04 moved a folder and updated 3d print slice
    [box 1.3 take2.3mf]
2023-04-05 updating 3d models for final draft
    [box box box.3mf, box try number i lost count.stl]
2023-04-05 PowerPoint update. new PCB screenshots
2023-04-09 updated Raindrops button press placements
2023-04-09 forgot to add file drafts to last push. uwu
    [box 1.3 take2.3mf, cyberinetV1.3finalIHope.stl]
2023-04-13 final draft of materials for lecture recital
2023-04-16 penultimate recital push. any updates are for small bug-fixes.
    only until 04/19
    [CyberinetV1.3_orig.ino, Cyberinet_V1.3BT.ino, Cyberinet_V1.3_edited.ino]
2023-04-22 added pdf of powerpoint slides
2023-04-26 upadting improv and receive with gyro/accel scales
2023-04-26 more file organizing and new UI for CNET.rangeSet
    [Main Boardv1.1_contour.gm1, Main Boardv1.1_copperBottom.gbl, Main Boardv1.1_copperTop.gtl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]
2023-04-28 update sensor labels for data transmission
2023-05-08 updates and diagrams for more document stuff. final scores are next.
    [micBasic.fzz, thumbjoystick.fzz]
2023-05-12 add 4-8 presets for all help patches. CNET.reverb~ currently broken
2023-05-13 making CNET.switch and updating Max version
2023-05-13 folder rename. pushing to avoid thousands of file updates.
    [Cyberinet main Box (3).stl, Cyberinet v 1.3Final Draft PLA.3mf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]
